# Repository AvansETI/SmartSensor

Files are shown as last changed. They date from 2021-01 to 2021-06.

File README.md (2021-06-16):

# SmartSensor
Author: _Maurice Snoeren (Lectoraat Smart Energy en Datascience & ICT)_


_Note: Current hardware version 1.0 is under test and some issues have been found ... it will be updated soon!_

De SmartSensor is een resultaat van verschillende onderzoeken sinds 2018. Focus is gegeven aan laag vermogen, controle over energiestromen en eenvoud. Deze SmartSensor wordt binnen onderzoek en onderwijs toegepast.

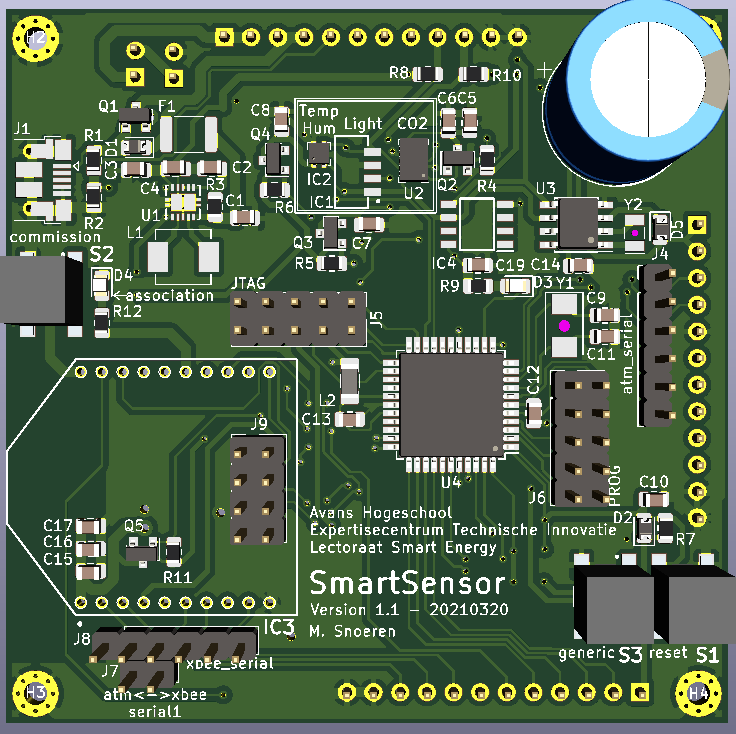
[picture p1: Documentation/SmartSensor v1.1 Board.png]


_3D generated model_

## Inleiding
Meten is weten! Het belang van meten en het verzamelen van informatie is wel bekend. Echter komt het vaak  voor dat data niet voorhanden is of dat de data van beschikbare systemen van onvoldoende kwaliteit is. Bestaande meetsystemen zijn vaak kostbaar en onvoldoende flexibel om de benodigde aanpassingen te maken die nodig zijn binnen de verschillende onderzoeken. De SmartSensor biedt een open platform, waarmee eenvoudig vele meetpunten in een omgeving geïnstalleerd kunnen worden. Het platform biedt de mogelijkheid eigen metingen toe te voegen. Uniek is dat het met de SmartSensor mogelijk wordt om met andere systemen te communiceren. Hierdoor wordt het mogelijk om tevens sturing aan te brengen. Een open platform dat binnen Avans Hogeschool wordt ingezet voor het onderzoek en onderwijs.

## SmartSensor specificatie
- Atmega324PB (Microcontroller)
- ATECC608B (Trusted Platform Module)
- Zigbee module (of nRF24L01)
- Real-time klok
- Omgevingslichtsensor (0lx t/m 167klx, 5mlx res.) 
- Temperatuursensor (±0.5˚C, -40 t/m 100˚C)
- Luchtvochtigheidssensor (±4.5 %RH)
- CO2 sensor (optional, eCO2, 400 t/m 8192ppm) 
- Interfaces: RS232 (3.3V), I2C en SPI
- Uitbreiden met header

## Werking
Alle SmartSensoren staan met elkaar in verbinding door middel van een Zigbee mesh-netwerk. Eén van de sensoren dient als een coördinator te dienen om de meet¬gegevens uit het systeem te krijgen. Via deze coördinator kunnen tevens commando’s naar de verschillende sensoren gestuurd worden om bijvoorbeeld een batterij op te laden of de verwarming in te stellen op 20 graden Celsius.

## Metingen bestaande gebouwen
Door op verschillende punten te meten, krijgt men inzicht in de energiehuishouding van het bestaande gebouw. In veel (oude) gebouwen zijn er geen of onvoldoende meetpunten aanwezig. Met behulp van de SmartSensor kunnen deze meetpunten eenvoudig worden toegevoegd. Doordat met gebouwsystemen communiceert kan worden, is het tevens mogelijk de gegevens van deze systemen te verzamelen en mee te nemen in de analyse.

## Verduurzaming gebouwen
Binnen gebouwen kan de SmartSensor meetpunten realiseren én communiceren met gebouwsystemen. Hierdoor wordt het mogelijk om een regelsysteem te realiseren waarbij het gebouw kan worden verduurzaamd. Gebouwsystemen worden dan aangestuurd op basis van verschillende metingen. Door de flexibiliteit van deze SmartSensor wordt het eenvoudig om verschillende strategieën en technieken te onderzoeken en ontdekken.

## Nieuwbouw
Nieuwe gebouwen worden vaak opgeleverd met veel sensoren en gebouwbeheersystemen. Meer meetpunten is vaak niet nodig. In dit geval is het mogelijk om de SmartSensor te gebruiken om het gebouw-beheersysteem te valideren. Door vele metingen aan te brengen krijgt men inzicht in de kwaliteit en effectiviteit van het bestaande systeem. Daarnaast is het mogelijk om met de SmartSensor eenvoudig extra meetpunten aan te brengen binnen het gebouw.

## Onderzoek
De SmartSensor speelt steeds meer een rol binnen de onderzoeken naar slimme duurzame energiesystemen, datascience vraagstukken en het zelfbewuste huis.

## Interesse
Interesse voor samenwerking? Neem contact met ons op!

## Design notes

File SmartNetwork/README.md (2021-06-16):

# SmartNetwork

The MQTT bus has been made smart with all kinds of messages and specific protocol.
It purpose is to create a safe sensor environment in which sensors can push data
and know that the integrity of the data is correct! This document is used to create
the documentation of this network.

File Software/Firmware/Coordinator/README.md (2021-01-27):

# Coordinator

Coordinator ontwikkeld om de data van de SmartSensor te ontvangen en die door te sturen over MQTT.
Voor development is Platformio gebruikt. Arduino Uno met een Zigbee Shield en een WiFi shield gebruikt. De Zigbee module moet wel ingesteld worden via DIGI XCTU. PANID, AT modus.

## Configuratie
Er is een config-template.h bestand in de include folder hier kan de WiFi en MQTT configuratie aangepast worden.

## Data 
Er wordt vanuit de Smart Sensor een JSON gestuurd die wordt uitgelezen met de Coordinator, in de Coordinator wordt er gecheckt of het een valide JSON is, zo ja dan wordt doorgestuurd naar een MQTT server die je hebt ingesteld in de configuratiebestand.

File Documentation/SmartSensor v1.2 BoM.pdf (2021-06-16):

SmartSensor v1.2 - 20210616
Item Qty Reference(s) | Value
1 | 4 C1, C3, C4, C17 | 10uF
2 | 9 C2, C5, C7, C8, C10, C12, C13, C14, C19 100nF
3 | 2 C6, C16 | 1uF
4 | 2 C9, C11 | 22pF
5 | 1 C15 | 8.2pF
6 | 1 C18 | 1F
7 | 3 D1, D2, D5 | D_Small
8 | 2 D3, D4 | RED
9 | 1 D6 | GREEN
10 | 1 F1 | Polyfuse_Small
12 | 1 IC1 | VEML7700-TT
13 | 1 IC2 | SHTC3
14 | 1 IC3 | XB24CZ7PIT-004
15 | 1 IC4 | ATECC608B-SSHDA-B
16 | 1 J1 | USB_B_Micro
26 | 1 L1 | 2.2uH @ 2,5A
27 | 1 L2 | 4.7uH
28 | 1 Q1 | DMG2301L
29 | 2 R1, R5 | 100k
30 | 1 R2 | 200k
31 | 1 R3 | 100
32 | 1 R7 | 10k
33 | 2 R8, R10 | 2.2k
34 | 3 R4, R9, R12 | 210
35 | 3 S1, S2, S3 | Push button
37 | 1 U1 | TPS63001
38 | 1 U2 | CCS811
39 | 1 U3 | MCP7940N-xSN
40 | 1 U4 | ATmega324PB-AU
41 | 1 Y1 | 20MHz
42 | 1 Y2 | Crystal

LibPart
Device:C_Small
Device:C_Small
Device:C_Small
Device:C_Small
Device:C_Small
Device:CP
Device:D_Small
Device:LED_Small
Device:LED_Small
Device:Polyfuse_Small
VEML7700-TT:VEML7700-TT
SamacSys_Parts:SHTC3
XB24CZ7PIT-004:XB24CZ7PIT-004 ATECC608B-SSHDA-B:ATECC608B-SSHDA-B Connector:USB_B_Micro
Device:L_Small
Device:L_Small
Transistor_FET:DMG2301L
Device:R_Small
Device:R_Small
Device:R_Small
Device:R_Small
Device:R_Small
Device:R_Small
Switch:SW_Push
Regulator_Switching:TPS63001 Sensor_Gas:CCS811
Timer:MCP7940N-xSN
MCU_Microchip_ATmega:ATmega324PB-AU Device:Crystal
Device:Crystal

Footprint | Manufacturer number
Capacitor_SMD:C_0805_2012Metric | 08056D106KAT4A (https://nl.mouser.com/ProductDetail/AVX/08056D106KAT4A/)
Capacitor_SMD:C_0805_2012Metric | 08055C104KAT2A (https://nl.mouser.com/ProductDetail/AVX/08055C104KAT2A/?qs=2ujN4bDBNE9mJvapP%252BjopA%3D%3D)
Capacitor_SMD:C_0805_2012Metric | C0805C105K4RAC (https://nl.mouser.com/ProductDetail/KEMET/C0805C105K4RAC/?qs=esDHISMOsl1mFkfcv5ZyKg%3D%3D)
Capacitor_SMD:C_0805_2012Metric | C0805C220K1HACTU (https://nl.mouser.com/ProductDetail/KEMET/C0805C220K1HACTU/?qs=W0yvOO0ixfHaPTgNXyVDyQ%3D%3D)
Capacitor_SMD:C_0805_2012Metric | C0805C829C1HACAUTO (https://nl.mouser.com/ProductDetail/KEMET/C0805C829C1HACAUTO/?qs=j%252B1pi9TdxUbIPgXf8DZVCg%3D%3D)
Capacitor_THT:CP_Radial_D14.0mm_P5.00mm | FGR0H105ZF (https://nl.mouser.com/ProductDetail/KEMET/FGR0H105ZF)
Diode_SMD:D_0805_2012Metric | NSVR1020MW2T1G (https://nl.mouser.com/ProductDetail/ON-Semiconductor/NSVR1020MW2T1G/)
LED_SMD:LED_0805_2012Metric | 150080SS75000 (https://nl.mouser.com/ProductDetail/Wurth-Elektronik/150080SS75000/?qs=LlUlMxKIyB2zzpiaOzrUdw%3D%3D)
LED_SMD:LED_0805_2012Metric | 150080GS75000 (https://nl.mouser.com/ProductDetail/Wurth-Elektronik/150080GS75000?qs=2kOmHSv6VfQRoTEZVk1mGA%3D%3D)
Fuse:Fuse_1812_4532Metric | 1812L300MR (https://nl.mouser.com/ProductDetail/Littelfuse/1812L300MR/?qs=fp%2Fo%2FcJ74okPZmQQaLnihw%3D%3D)
SmartSensor:VEML7700 | VEML7700-TT (https://nl.mouser.com/ProductDetail/Vishay-Semiconductors/VEML7700-TT/)
Package_DFN_QFN:AMS_QFN-4-1EP_2x2mm_P0.95mm_EP0.7x1.6mm | SHTC3 (https://nl.mouser.com/ProductDetail/Sensirion/SHTC3/?qs=y6ZabgHbY%252Bx3LlA87fqBwg%3D%3D)
XB24CZ7PIT-004:XB24CAPIT-001 | XB24CAWIT-001 (https://nl.mouser.com/ProductDetail/DIGI/XB24CAWIT-001)
ATECC608B-SSHDA-B:SOIC127P600X175-8N | ATECC608B-SSHDA-B (https://nl.mouser.com/ProductDetail/Microchip-Technology/ATECC608B-SSHDA-B/)
Connector_USB:USB_Micro-B_Amphenol_10103594-0001LF_Horizontal | 10103594-0001LF (https://nl.mouser.com/ProductDetail/Amphenol-FCI/10103594-0001LF)
Inductor_SMD:L_Vishay_IHLP-2020 | IHLP2020CZER2R2M11 (https://nl.mouser.com/ProductDetail/Vishay-Dale/IHLP2020CZER2R2M11/?qs=6luCnr706CzLTrsnHEyf2A%3D%3D)
Inductor_SMD:L_1206_3216Metric_Pad1.42x1.75mm_HandSolder | AIML-1206-4R7K-T (https://nl.mouser.com/ProductDetail/ABRACON/AIML-1206-4R7K-T?qs=1vO2EIVe%252BY78r6VHt%252BJPBQ%3D%3D)
Package_TO_SOT_SMD:SOT-23 | DMG2301LK-7 (https://nl.mouser.com/ProductDetail/Diodes-Incorporated/DMG2301LK-7/)
Resistor_SMD:R_0805_2012Metric | RN73H2ATTD1003B25 (https://nl.mouser.com/ProductDetail/KOA-Speer/RN73H2ATTD1003B25/?qs=pJKkPLTLvBjWE0HE4eur%2FQ%3D%3D)
Resistor_SMD:R_0805_2012Metric | RN73H2ATTD2003B25 (https://nl.mouser.com/ProductDetail/KOA-Speer/RN73H2ATTD2003B25/?qs=pJKkPLTLvBgFU%2FmyE2p5oQ%3D%3D)
Resistor_SMD:R_0805_2012Metric | RN73H2ATTD1000B25 (https://nl.mouser.com/ProductDetail/KOA-Speer/RN73H2ATTD1000B25/?qs=2eXtorxHpEIlNXER6IsTWA%3D%3D)
Resistor_SMD:R_0805_2012Metric | RN73H2ATTD1002B25 (https://nl.mouser.com/ProductDetail/KOA-Speer/RN73H2ATTD1002B25/?qs=ql2sB4ohmgACaXI2i5iccA%3D%3D)
Resistor_SMD:R_0805_2012Metric | RN73H2ATTD2201B10 (https://nl.mouser.com/ProductDetail/KOA-Speer/RN73H2ATTD2201B10/?qs=pJKkPLTLvBhl2%252Bb4W7%252BSoQ%3D%3D)
Resistor_SMD:R_0805_2012Metric | RN73H2ATTD2100B25 (https://nl.mouser.com/ProductDetail/KOA-Speer/RN73H2ATTD2100B25/?qs=pJKkPLTLvBgPs88Lelxj0w%3D%3D)
LL3301AF065QJ:LL3301FF065QJ | LL3301FF065QJ (https://nl.mouser.com/ProductDetail/E-Switch/LL3301FF065QJ/)
Package_SON:Texas_DRC0010J_ThermalVias | TPS63001DRCR (https://nl.mouser.com/ProductDetail/Texas-Instruments/TPS63001DRCR/?qs=QZuYiDxzHagn01UZf%2F%252B1Bw%3D%3D)
Package_LGA:AMS_LGA-10-1EP_2.7x4mm_P0.6mm | CCS811B-JOPR (https://nl.mouser.com/ProductDetail/ScioSense/CCS811B-JOPR/?qs=DPoM0jnrROVuOwd2mTsTQg%3D%3D)
Package_SO:SOIC-8_3.9x4.9mm_P1.27mm | MCP7940N-I/SN (https://nl.mouser.com/ProductDetail/Microchip-Technology/MCP7940N-I-SN/?qs=o%2FJGMiCJeCOTsMP4nrR5Uw%3D%3D)
Package_QFP:TQFP-44_10x10mm_P0.8mm | ATMEGA324PB-AU (https://nl.mouser.com/ProductDetail/556-ATMEGA324PBAU/)
Crystal:Crystal_SMD_Abracon_ABM3-2Pin_5.0x3.2mm | ABM3AIG-20.000MHZ-8-1R-T (https://nl.mouser.com/ProductDetail/ABRACON/ABM3AIG-20000MHZ-8-1R-T/?qs=uwxL4vQweFPdWRyKGKRehg%3D%3D)
Crystal:Crystal_SMD_G8-2Pin_3.2x1.5mm | ABS07W-32.768kHz-K-1-T (https://nl.mouser.com/ProductDetail/ABRACON/ABS07W-32768kHz-K-1-T/?qs=gt1LBUVyoHnktSE7ztRl4g%3D%3D)

Remark
Standard component can be found anywhere Standard component can be found anywhere Standard component can be found anywhere Standard component can be found anywhere Standard component can be found anywhere Normally not for Elines B.V.
Standard component can be found anywhere Standard component can be found anywhere Standard component can be found anywhere

Normally not for Elines B.V.

Aangepast naar 1206

Standard component can be found anywhere Standard component can be found anywhere Standard component can be found anywhere Standard component can be found anywhere Standard component can be found anywhere Standard component can be found anywhere

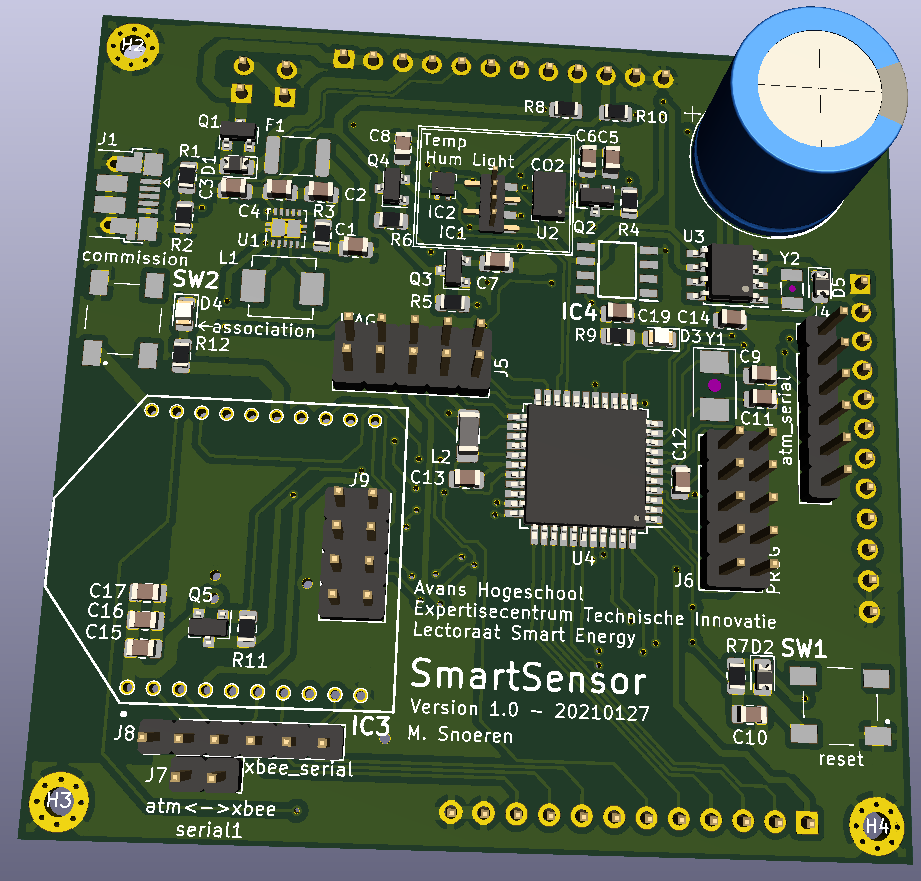
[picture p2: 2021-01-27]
Documentation/SmartSensor v1.0 Board.png

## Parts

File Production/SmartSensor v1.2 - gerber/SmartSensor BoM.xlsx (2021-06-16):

 |  | SmartSensor v1.2 - 20210616
Item | Qty | Reference(s) | Value | LibPart | Footprint | Manufacturer number | Remark
1 | 4 | C1, C3, C4, C17 | 10uF | Device:C_Small | Capacitor_SMD:C_0805_2012Metric | 08056D106KAT4A (https://nl.mouser.com/ProductDetail/AVX/08056D106KAT4A/) | Standard component can be found anywhere
2 | 9 | C2, C5, C7, C8, C10, C12, C13, C14, C19 | 100nF | Device:C_Small | Capacitor_SMD:C_0805_2012Metric | 08055C104KAT2A (https://nl.mouser.com/ProductDetail/AVX/08055C104KAT2A/?qs=2ujN4bDBNE9mJvapP%252BjopA%3D%3D) | Standard component can be found anywhere
3 | 2 | C6, C16 | 1uF | Device:C_Small | Capacitor_SMD:C_0805_2012Metric | C0805C105K4RAC (https://nl.mouser.com/ProductDetail/KEMET/C0805C105K4RAC/?qs=esDHISMOsl1mFkfcv5ZyKg%3D%3D) | Standard component can be found anywhere
4 | 2 | C9, C11 | 22pF | Device:C_Small | Capacitor_SMD:C_0805_2012Metric | C0805C220K1HACTU (https://nl.mouser.com/ProductDetail/KEMET/C0805C220K1HACTU/?qs=W0yvOO0ixfHaPTgNXyVDyQ%3D%3D) | Standard component can be found anywhere
5 | 1 | C15 | 8.2pF | Device:C_Small | Capacitor_SMD:C_0805_2012Metric | C0805C829C1HACAUTO (https://nl.mouser.com/ProductDetail/KEMET/C0805C829C1HACAUTO/?qs=j%252B1pi9TdxUbIPgXf8DZVCg%3D%3D) | Standard component can be found anywhere
6 | 1 | C18 | 1F | Device:CP | Capacitor_THT:CP_Radial_D14.0mm_P5.00mm | FGR0H105ZF (https://nl.mouser.com/ProductDetail/KEMET/FGR0H105ZF) | Normally not for Elines B.V.
7 | 3 | D1, D2, D5 | D_Small | Device:D_Small | Diode_SMD:D_0805_2012Metric | NSVR1020MW2T1G (https://nl.mouser.com/ProductDetail/ON-Semiconductor/NSVR1020MW2T1G/) | Standard component can be found anywhere
8 | 2 | D3, D4 | RED | Device:LED_Small | LED_SMD:LED_0805_2012Metric | 150080SS75000 (https://nl.mouser.com/ProductDetail/Wurth-Elektronik/150080SS75000/?qs=LlUlMxKIyB2zzpiaOzrUdw%3D%3D) | Standard component can be found anywhere
9 | 1 | D6 | GREEN | Device:LED_Small | LED_SMD:LED_0805_2012Metric | 150080GS75000 (https://nl.mouser.com/ProductDetail/Wurth-Elektronik/150080GS75000?qs=2kOmHSv6VfQRoTEZVk1mGA%3D%3D) | Standard component can be found anywhere
10 | 1 | F1 | Polyfuse_Small | Device:Polyfuse_Small | Fuse:Fuse_1812_4532Metric | 1812L300MR (https://nl.mouser.com/ProductDetail/Littelfuse/1812L300MR/?qs=fp%2Fo%2FcJ74okPZmQQaLnihw%3D%3D)
12 | 1 | IC1 | VEML7700-TT | VEML7700-TT:VEML7700-TT | SmartSensor:VEML7700 | VEML7700-TT (https://nl.mouser.com/ProductDetail/Vishay-Semiconductors/VEML7700-TT/)
13 | 1 | IC2 | SHTC3 | SamacSys_Parts:SHTC3 | Package_DFN_QFN:AMS_QFN-4-1EP_2x2mm_P0.95mm_EP0.7x1.6mm | SHTC3 (https://nl.mouser.com/ProductDetail/Sensirion/SHTC3/?qs=y6ZabgHbY%252Bx3LlA87fqBwg%3D%3D)
14 | 1 | IC3 | XB24CZ7PIT-004 | XB24CZ7PIT-004:XB24CZ7PIT-004 | XB24CZ7PIT-004:XB24CAPIT-001 | XB24CAWIT-001 (https://nl.mouser.com/ProductDetail/DIGI/XB24CAWIT-001) | Normally not for Elines B.V.
15 | 1 | IC4 | ATECC608B-SSHDA-B | ATECC608B-SSHDA-B:ATECC608B-SSHDA-B | ATECC608B-SSHDA-B:SOIC127P600X175-8N | ATECC608B-SSHDA-B (https://nl.mouser.com/ProductDetail/Microchip-Technology/ATECC608B-SSHDA-B/)
16 | 1 | J1 | USB_B_Micro | Connector:USB_B_Micro | Connector_USB:USB_Micro-B_Amphenol_10103594-0001LF_Horizontal | 10103594-0001LF (https://nl.mouser.com/ProductDetail/Amphenol-FCI/10103594-0001LF)
26 | 1 | L1 | 2.2uH @ 2,5A | Device:L_Small | Inductor_SMD:L_Vishay_IHLP-2020 | IHLP2020CZER2R2M11 (https://nl.mouser.com/ProductDetail/Vishay-Dale/IHLP2020CZER2R2M11/?qs=6luCnr706CzLTrsnHEyf2A%3D%3D)
27 | 1 | L2 | 4.7uH | Device:L_Small | Inductor_SMD:L_1206_3216Metric_Pad1.42x1.75mm_HandSolder | AIML-1206-4R7K-T (https://nl.mouser.com/ProductDetail/ABRACON/AIML-1206-4R7K-T?qs=1vO2EIVe%252BY78r6VHt%252BJPBQ%3D%3D) | Aangepast naar 1206
28 | 1 | Q1 | DMG2301L | Transistor_FET:DMG2301L | Package_TO_SOT_SMD:SOT-23 | DMG2301LK-7 (https://nl.mouser.com/ProductDetail/Diodes-Incorporated/DMG2301LK-7/)
29 | 2 | R1, R5 | 100k | Device:R_Small | Resistor_SMD:R_0805_2012Metric | RN73H2ATTD1003B25 (https://nl.mouser.com/ProductDetail/KOA-Speer/RN73H2ATTD1003B25/?qs=pJKkPLTLvBjWE0HE4eur%2FQ%3D%3D) | Standard component can be found anywhere
30 | 1 | R2 | 200k | Device:R_Small | Resistor_SMD:R_0805_2012Metric | RN73H2ATTD2003B25 (https://nl.mouser.com/ProductDetail/KOA-Speer/RN73H2ATTD2003B25/?qs=pJKkPLTLvBgFU%2FmyE2p5oQ%3D%3D) | Standard component can be found anywhere
31 | 1 | R3 | 100 | Device:R_Small | Resistor_SMD:R_0805_2012Metric | RN73H2ATTD1000B25 (https://nl.mouser.com/ProductDetail/KOA-Speer/RN73H2ATTD1000B25/?qs=2eXtorxHpEIlNXER6IsTWA%3D%3D) | Standard component can be found anywhere
32 | 1 | R7 | 10k | Device:R_Small | Resistor_SMD:R_0805_2012Metric | RN73H2ATTD1002B25 (https://nl.mouser.com/ProductDetail/KOA-Speer/RN73H2ATTD1002B25/?qs=ql2sB4ohmgACaXI2i5iccA%3D%3D) | Standard component can be found anywhere
33 | 2 | R8, R10 | 2.2k | Device:R_Small | Resistor_SMD:R_0805_2012Metric | RN73H2ATTD2201B10 (https://nl.mouser.com/ProductDetail/KOA-Speer/RN73H2ATTD2201B10/?qs=pJKkPLTLvBhl2%252Bb4W7%252BSoQ%3D%3D) | Standard component can be found anywhere
34 | 3 | R4, R9, R12 | 210 | Device:R_Small | Resistor_SMD:R_0805_2012Metric | RN73H2ATTD2100B25 (https://nl.mouser.com/ProductDetail/KOA-Speer/RN73H2ATTD2100B25/?qs=pJKkPLTLvBgPs88Lelxj0w%3D%3D) | Standard component can be found anywhere
35 | 3 | S1, S2, S3 | Push button | Switch:SW_Push | LL3301AF065QJ:LL3301FF065QJ | LL3301FF065QJ (https://nl.mouser.com/ProductDetail/E-Switch/LL3301FF065QJ/)
37 | 1 | U1 | TPS63001 | Regulator_Switching:TPS63001 | Package_SON:Texas_DRC0010J_ThermalVias | TPS63001DRCR (https://nl.mouser.com/ProductDetail/Texas-Instruments/TPS63001DRCR/?qs=QZuYiDxzHagn01UZf%2F%252B1Bw%3D%3D)
38 | 1 | U2 | CCS811 | Sensor_Gas:CCS811 | Package_LGA:AMS_LGA-10-1EP_2.7x4mm_P0.6mm | CCS811B-JOPR (https://nl.mouser.com/ProductDetail/ScioSense/CCS811B-JOPR/?qs=DPoM0jnrROVuOwd2mTsTQg%3D%3D)
39 | 1 | U3 | MCP7940N-xSN | Timer:MCP7940N-xSN | Package_SO:SOIC-8_3.9x4.9mm_P1.27mm | MCP7940N-I/SN (https://nl.mouser.com/ProductDetail/Microchip-Technology/MCP7940N-I-SN/?qs=o%2FJGMiCJeCOTsMP4nrR5Uw%3D%3D)
40 | 1 | U4 | ATmega324PB-AU | MCU_Microchip_ATmega:ATmega324PB-AU | Package_QFP:TQFP-44_10x10mm_P0.8mm | ATMEGA324PB-AU (https://nl.mouser.com/ProductDetail/556-ATMEGA324PBAU/)
41 | 1 | Y1 | 20MHz | Device:Crystal | Crystal:Crystal_SMD_Abracon_ABM3-2Pin_5.0x3.2mm | ABM3AIG-20.000MHZ-8-1R-T (https://nl.mouser.com/ProductDetail/ABRACON/ABM3AIG-20000MHZ-8-1R-T/?qs=uwxL4vQweFPdWRyKGKRehg%3D%3D)
42 | 1 | Y2 | Crystal | Device:Crystal | Crystal:Crystal_SMD_G8-2Pin_3.2x1.5mm | ABS07W-32.768kHz-K-1-T (https://nl.mouser.com/ProductDetail/ABRACON/ABS07W-32768kHz-K-1-T/?qs=gt1LBUVyoHnktSE7ztRl4g%3D%3D)

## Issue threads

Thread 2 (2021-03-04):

Hardware version 1.0 issues

macsnoeren, 2021-03-04:
The following issues have been found that will be fixed as soon as possible:
- USB connector wrong type. At this moment the pins have been mirrored.
- Tacticle switches wrong package. At this moment 90 degrees rotated that results in continuous reset.
- All MOSFETs have been connected reversed, resulting in always switched one via de diode.
- The light sensor has been connected reversed. Make sure the correct package is used!

macsnoeren, 2021-03-19:
Progress:

- USB connector wrong type => Indeed wrong type orderen. BOM updated. (check!)
- Tacticle switches wrong package. At this moment 90 degrees rotated that results in continuous reset.
- All MOSFETs have been connected reversed, resulting in always switched one via de diode => All MOSFETs mirrored. (check!)
- The light sensor has been connected reversed. Make sure the correct package is used => Light sensor was correctly connected.

macsnoeren, 2021-03-20:
Progress:

- USB connector wrong type => Indeed wrong type orderen. BOM updated. (check!)
- Tacticle switches wrong package. At this moment 90 degrees rotated that results in continuous reset. => New package (check!)
- All MOSFETs have been connected reversed, resulting in always switched one via de diode => All MOSFETs mirrored. (check!)
- The light sensor has been connected reversed. Make sure the correct package is used => Light sensor was correctly connected. => new package (check!)

macsnoeren, 2021-03-20:
Fixed the hardware, added a button.

Closed 2021-03-20.

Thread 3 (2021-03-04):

i2c not working properly

macsnoeren, 2021-03-04:
At this moment it is not possible to read and write to the various ICs.

macsnoeren, 2021-03-04:
Today, the board have been checked and it has been found that the light sensor has been place reversed. This IC has been removed for the moment. All other connections have been checked and it seems to be correctly connected.

macsnoeren, 2021-03-04:
The signals of the i2c bus have been checked using an oscilloscope. The signals are okay. When the CO2 sensor is selected, weird things happen. After the data, the SDA bus is pulled low by the device.I think, while we perform a read, the IC waits on a clock to give the data back the processor using SDA.

Try to read the following bytes and check if the sensor pushed data back!

macsnoeren, 2021-03-04:
TODO: The nWake pin of the CO2 sensor is not yet used. This pin needs to be driven low before the i2c bus is used. All GPIO pins of the Atmel are set to input without pullup when started up. Try to set the pinmode to output and drive it low at start up.

macsnoeren, 2021-03-04:
From the datasheet is has been found that the IC SHTC3 has a device address 0x70: 111 0000. So, when reading it will be 1110 0000 => E0. And writhing 1110 0001 => E1. Therefore, the address has been changed to E0 in the board support. Please use the address E0.

macsnoeren, 2021-03-04:
TODO: Please use 100kHz clock for the "normal mode" i2c operation.

macsnoeren, 2021-03-19:
FloBo, are you able to put some info in this issue page, while everything is working now. Except the CO2 sensor.

macsnoeren, 2021-03-21:
Found this at: [https://www.ti.com/lit/an/scaa106/scaa106.pdf?ts=1616331517789&ref_url=https%253A%252F%252Fwww.google.com%252F](https://www.ti.com/lit/an/scaa106/scaa106.pdf?ts=1616331517789&ref_url=https%253A%252F%252Fwww.google.com%252F)

Sorry, it is the definition of I2C that slaves must 'pull' the clock-line low to 'pace' a master when return-data is not immediately available.  And in ALL cases of microcontroller I2C slave implementations, they ALWAYS pull the clock-line low at every access as uC firmware must supply the return data 'after some time'.  Once you have initialized the K22F into I2C 'slave' mode, you are going to have to be sure that it is ALWAYS 'ready' to return data for I2C transactions addressed to it, else it will indeed permanently stall the whole I2C bus. If you don't want the K22F reacting to such transactions, you have to disable this slave mode (for at least those time periods).  Does your K22F respond to addressed transactions 'fully normally' when properly enabled?

Maybe, the CO2 sensor is busy initializing. We need to investigate this a bit more.

macsnoeren, 2021-03-21:
Some documentation:
[https://www.ti.com/lit/an/scaa106/scaa106.pdf?ts=1616331517789&ref_url=https%253A%252F%252Fwww.google.com%252F](https://www.ti.com/lit/an/scaa106/scaa106.pdf?ts=1616331517789&ref_url=https%253A%252F%252Fwww.google.com%252F)

macsnoeren, 2021-03-26:
Both I2C-busses are working properly. CO2 sensor is not working still. New issue will be created for this one.

Closed 2021-03-26.

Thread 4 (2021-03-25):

Hardware: SuperCap not current limited!

macsnoeren, 2021-03-25:
The used supercap is not current limited and will blow the fuse. Please make the hardware fix and put a resistor. In the new design, the resistor will be implemented.

macsnoeren, 2021-03-26:
Found out that the internal resistance is large and that means the current is already limited by the supercap itself.

Closed 2021-03-26.

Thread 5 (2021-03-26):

CO2 CSS811 not working

macsnoeren, 2021-03-26:
The CO2 sensor is not working on the board. It does not give an ACK and pulls for 25ms the datalines to low. When another CO2 break out board is connected, it works correctly. We assume that the hardware is failing at this moment.

Some docs:
https://cdn-learn.adafruit.com/downloads/pdf/adafruit-ccs811-air-quality-sensor.pdf
https://www.distrelec.nl/Web/Downloads/_t/ds/3566_eng_tds.pdf

macsnoeren, 2021-04-16:
The Adafruit CSS811 is working correctly, waiting on the prototypes.

macsnoeren, 2021-06-16:
Solved, everything is working now.

Closed 2021-06-16.

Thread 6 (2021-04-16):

Hardware v1.1 silkscreen incorrect VEML

macsnoeren, 2021-04-16:
Hardware silkscreen incorrect VEML.

macsnoeren, 2021-06-16:
Solved, everything is working now.

Closed 2021-06-16.

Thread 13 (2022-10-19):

SmartNetwork crash

macsnoeren, 2022-10-19:
```
|SmartNet | During handling of the above exception, another exception occurred:
0|SmartNet |
0|SmartNet | Traceback (most recent call last):
0|SmartNet |   File "/usr/lib/python3.8/threading.py", line 932, in _bootstrap_inner
0|SmartNet |     self.run()
0|SmartNet |   File "/usr/lib/python3.8/threading.py", line 870, in run
0|SmartNet |     self._target(*self._args, **self._kwargs)
0|SmartNet |   File "/home/maurice/.local/lib/python3.8/site-packages/paho/mqtt/client.py", line 3591, in _thread_main
0|SmartNet |     self.loop_forever(retry_first_connection=True)
0|SmartNet |   File "/home/maurice/.local/lib/python3.8/site-packages/paho/mqtt/client.py", line 1756, in loop_forever
0|SmartNet |     rc = self._loop(timeout)
0|SmartNet |   File "/home/maurice/.local/lib/python3.8/site-packages/paho/mqtt/client.py", line 1164, in _loop
0|SmartNet |     rc = self.loop_read()
0|SmartNet |   File "/home/maurice/.local/lib/python3.8/site-packages/paho/mqtt/client.py", line 1556, in loop_read
0|SmartNet |     rc = self._packet_read()
0|SmartNet |   File "/home/maurice/.local/lib/python3.8/site-packages/paho/mqtt/client.py", line 2439, in _packet_read
0|SmartNet |     rc = self._packet_handle()
0|SmartNet |   File "/home/maurice/.local/lib/python3.8/site-packages/paho/mqtt/client.py", line 3033, in _packet_handle
0|SmartNet |     return self._handle_publish()
0|SmartNet |   File "/home/maurice/.local/lib/python3.8/site-packages/paho/mqtt/client.py", line 3327, in _handle_publish
0|SmartNet |     self._handle_on_message(message)
0|SmartNet |   File "/home/maurice/.local/lib/python3.8/site-packages/paho/mqtt/client.py", line 3570, in _handle_on_message
0|SmartNet |     on_message(self, self._userdata, message)
0|SmartNet |   File "/home/maurice/SmartSensor/SmartNetwork/smartnetwork/smartnetwork/smartnetwork.py", line 79, in <lambda>
0|SmartNet |     self.mqtt.on_message    = lambda client, userdata, msg:       self.mqtt_on_message(client, userdata, msg)
0|SmartNet |   File "/home/maurice/SmartSensor/SmartNetwork/smartnetwork/smartnetwork/smartnetwork.py", line 119, in mqtt_on_message
0|SmartNet |     self.process_node_data(plJson)
0|SmartNet |   File "/home/maurice/SmartSensor/SmartNetwork/smartnetwork/smartnetwork/smartnetwork.py", line 231, in process_node_data
0|SmartNet |     node = self.get_node_from_id(data["id"])
0|SmartNet |   File "/home/maurice/SmartSensor/SmartNetwork/smartnetwork/smartnetwork/smartnetwork.py", line 172, in get_node_from_id
0|SmartNet |     records = self.query.query(org=self.org, query=query)
0|SmartNet |   File "/home/maurice/.local/lib/python3.8/site-packages/influxdb_client/client/query_api.py", line 100, in query
0|SmartNet |     response = self._query_api.post_query(org=org, query=self._create_query(query, self.default_dialect, params),
0|SmartNet |   File "/home/maurice/.local/lib/python3.8/site-packages/influxdb_client/service/query_service.py", line 258, in post_query
0|SmartNet |     (data) = self.post_query_with_http_info(**kwargs)  # noqa: E501
0|SmartNet |   File "/home/maurice/.local/lib/python3.8/site-packages/influxdb_client/service/query_service.py", line 338, in post_query_with_http_info
0|SmartNet |     return self.api_client.call_api(
0|SmartNet |   File "/home/maurice/.local/lib/python3.8/site-packages/influxdb_client/api_client.py", line 341, in call_api
0|SmartNet |     return self.__call_api(resource_path, method,
0|SmartNet |   File "/home/maurice/.local/lib/python3.8/site-packages/influxdb_client/api_client.py", line 171, in __call_api
0|SmartNet |     response_data = self.request(
0|SmartNet |   File "/home/maurice/.local/lib/python3.8/site-packages/influxdb_client/api_client.py", line 386, in request
0|SmartNet |     return self.rest_client.POST(url,
0|SmartNet |   File "/home/maurice/.local/lib/python3.8/site-packages/influxdb_client/rest.py", line 304, in POST
0|SmartNet |     return self.request("POST", url,
0|SmartNet |   File "/home/maurice/.local/lib/python3.8/site-packages/influxdb_client/rest.py", line 183, in request
0|SmartNet |     r = self.pool_manager.request(
0|SmartNet |   File "/usr/lib/python3/dist-packages/urllib3/request.py", line 79, in request
0|SmartNet |     return self.request_encode_body(
0|SmartNet |   File "/usr/lib/python3/dist-packages/urllib3/request.py", line 171, in request_encode_body
0|SmartNet |     return self.urlopen(method, url, **extra_kw)
0|SmartNet |   File "/usr/lib/python3/dist-packages/urllib3/poolmanager.py", line 330, in urlopen
0|SmartNet |     response = conn.urlopen(method, u.request_uri, **kw)
0|SmartNet |   File "/usr/lib/python3/dist-packages/urllib3/connectionpool.py", line 719, in urlopen
0|SmartNet |     retries = retries.increment(
0|SmartNet |   File "/usr/lib/python3/dist-packages/urllib3/util/retry.py", line 376, in increment
0|SmartNet |     raise six.reraise(type(error), error, _stacktrace)
0|SmartNet |   File "/usr/lib/python3/dist-packages/six.py", line 703, in reraise
0|SmartNet |     raise value
0|SmartNet |   File "/usr/lib/python3/dist-packages/urllib3/connectionpool.py", line 665, in urlopen
0|SmartNet |     httplib_response = self._make_request(
0|SmartNet |   File "/usr/lib/python3/dist-packages/urllib3/connectionpool.py", line 387, in _make_request
0|SmartNet |     conn.request(method, url, **httplib_request_kw)
0|SmartNet |   File "/usr/lib/python3.8/http/client.py", line 1256, in request
0|SmartNet |     self._send_request(method, url, body, headers, encode_chunked)
0|SmartNet |   File "/usr/lib/python3.8/http/client.py", line 1302, in _send_request
0|SmartNet |     self.endheaders(body, encode_chunked=encode_chunked)
0|SmartNet |   File "/usr/lib/python3.8/http/client.py", line 1251, in endheaders
0|SmartNet |     self._send_output(message_body, encode_chunked=encode_chunked)
0|SmartNet |   File "/usr/lib/python3.8/http/client.py", line 1011, in _send_output
0|SmartNet |     self.send(msg)
0|SmartNet |   File "/usr/lib/python3.8/http/client.py", line 951, in send
0|SmartNet |     self.connect()
0|SmartNet |   File "/usr/lib/python3/dist-packages/urllib3/connection.py", line 187, in connect
0|SmartNet |     conn = self._new_conn()
0|SmartNet |   File "/usr/lib/python3/dist-packages/urllib3/connection.py", line 171, in _new_conn
0|SmartNet |     raise NewConnectionError(
0|SmartNet | urllib3.exceptions.NewConnectionError: <urllib3.connection.HTTPConnection object at 0x7fe0720dc4f0>: Failed to establish a new connection: [Errno 111] Connection refused
```

macsnoeren, 2022-10-19:
Same issue as #12

macsnoeren, 2022-10-19:
Close this issue and work on #12

Closed 2022-10-19.

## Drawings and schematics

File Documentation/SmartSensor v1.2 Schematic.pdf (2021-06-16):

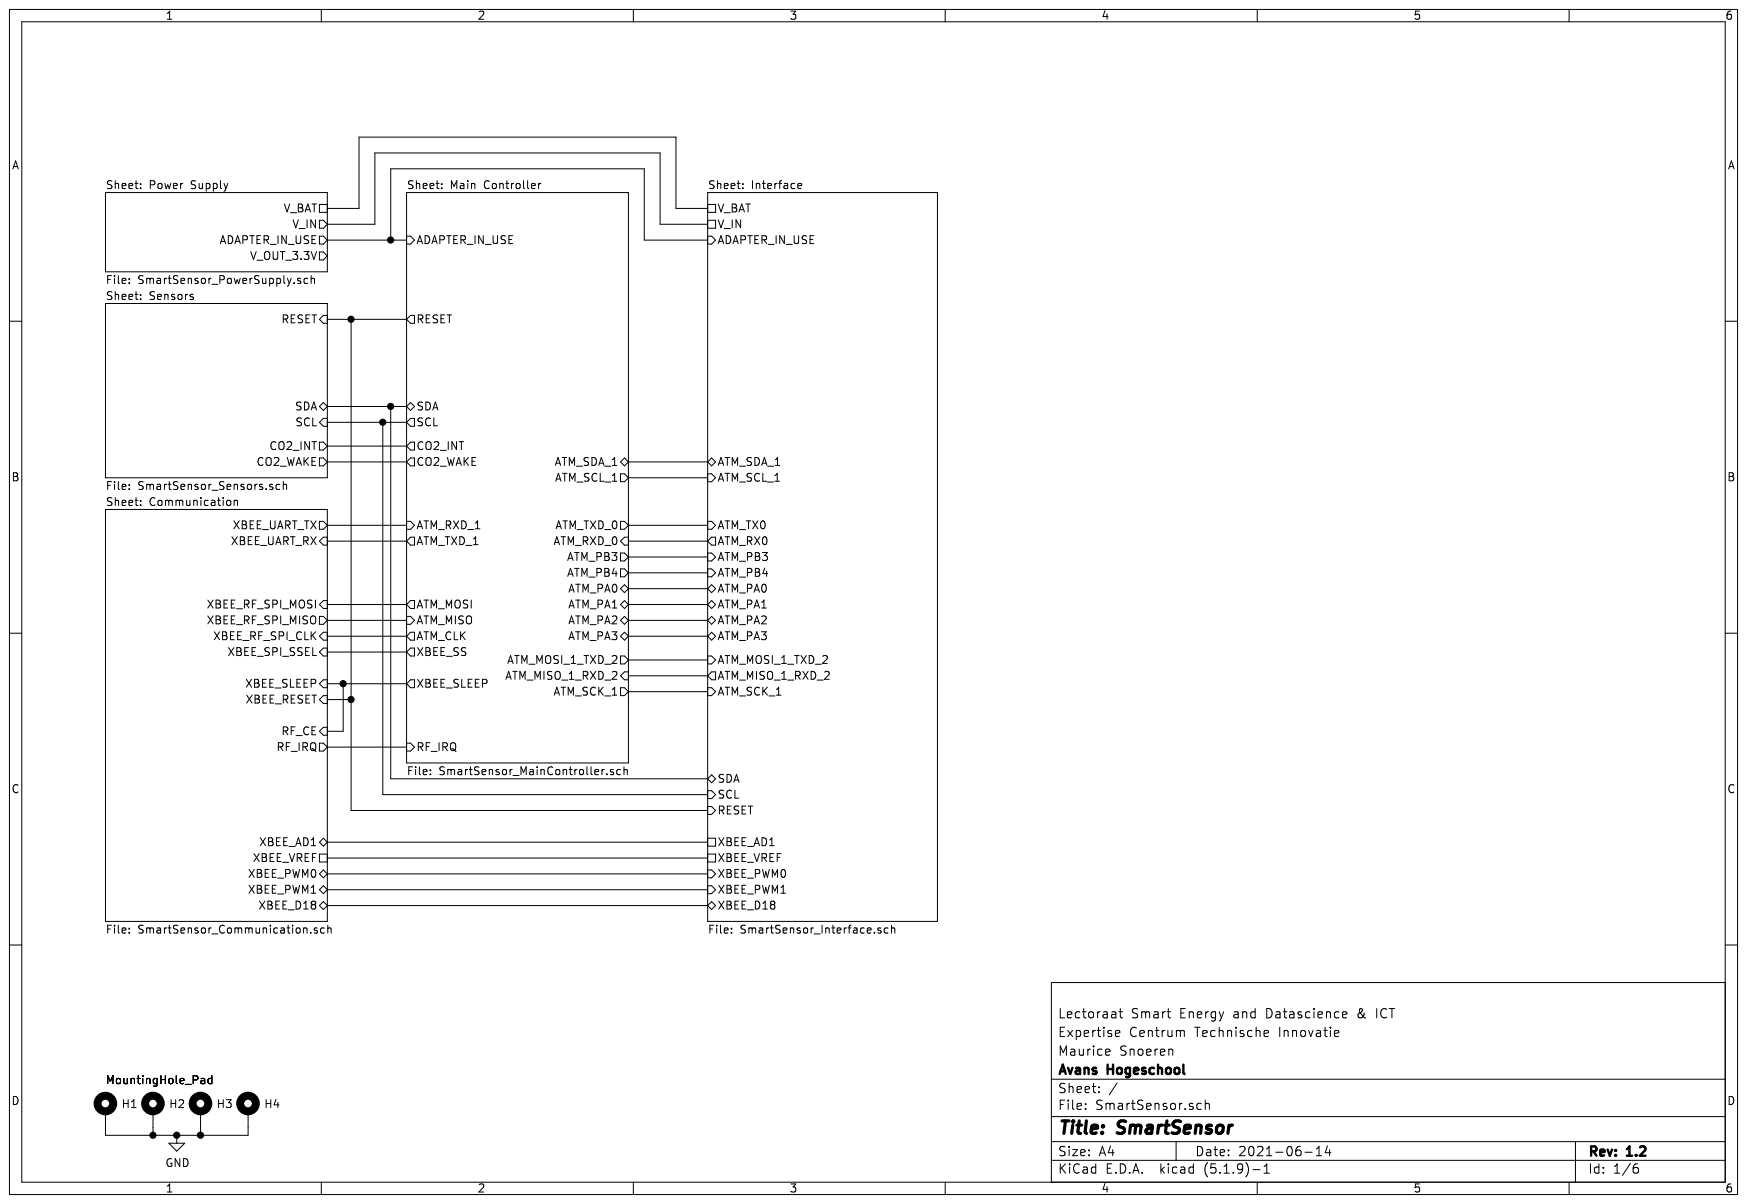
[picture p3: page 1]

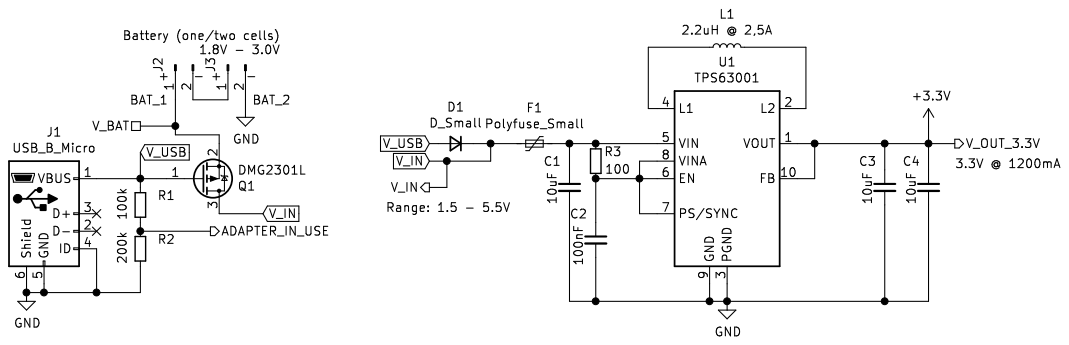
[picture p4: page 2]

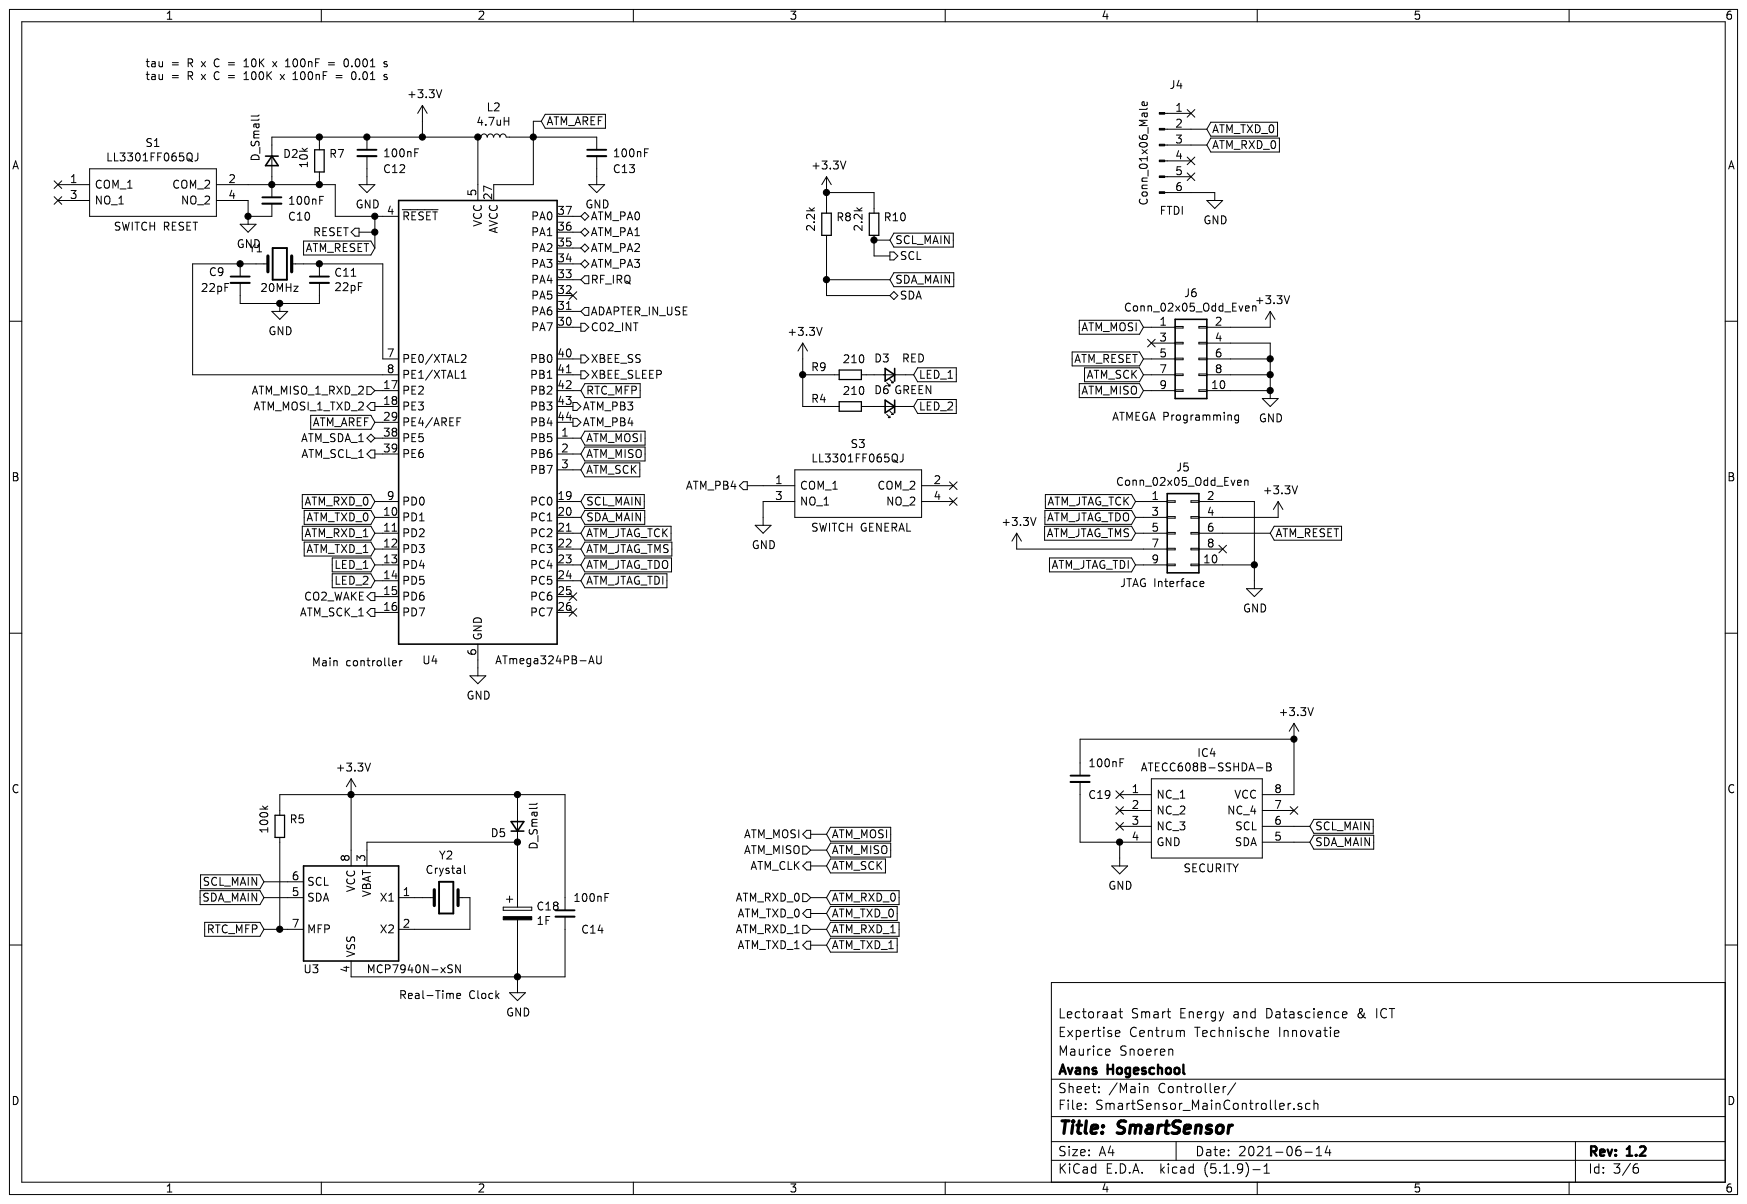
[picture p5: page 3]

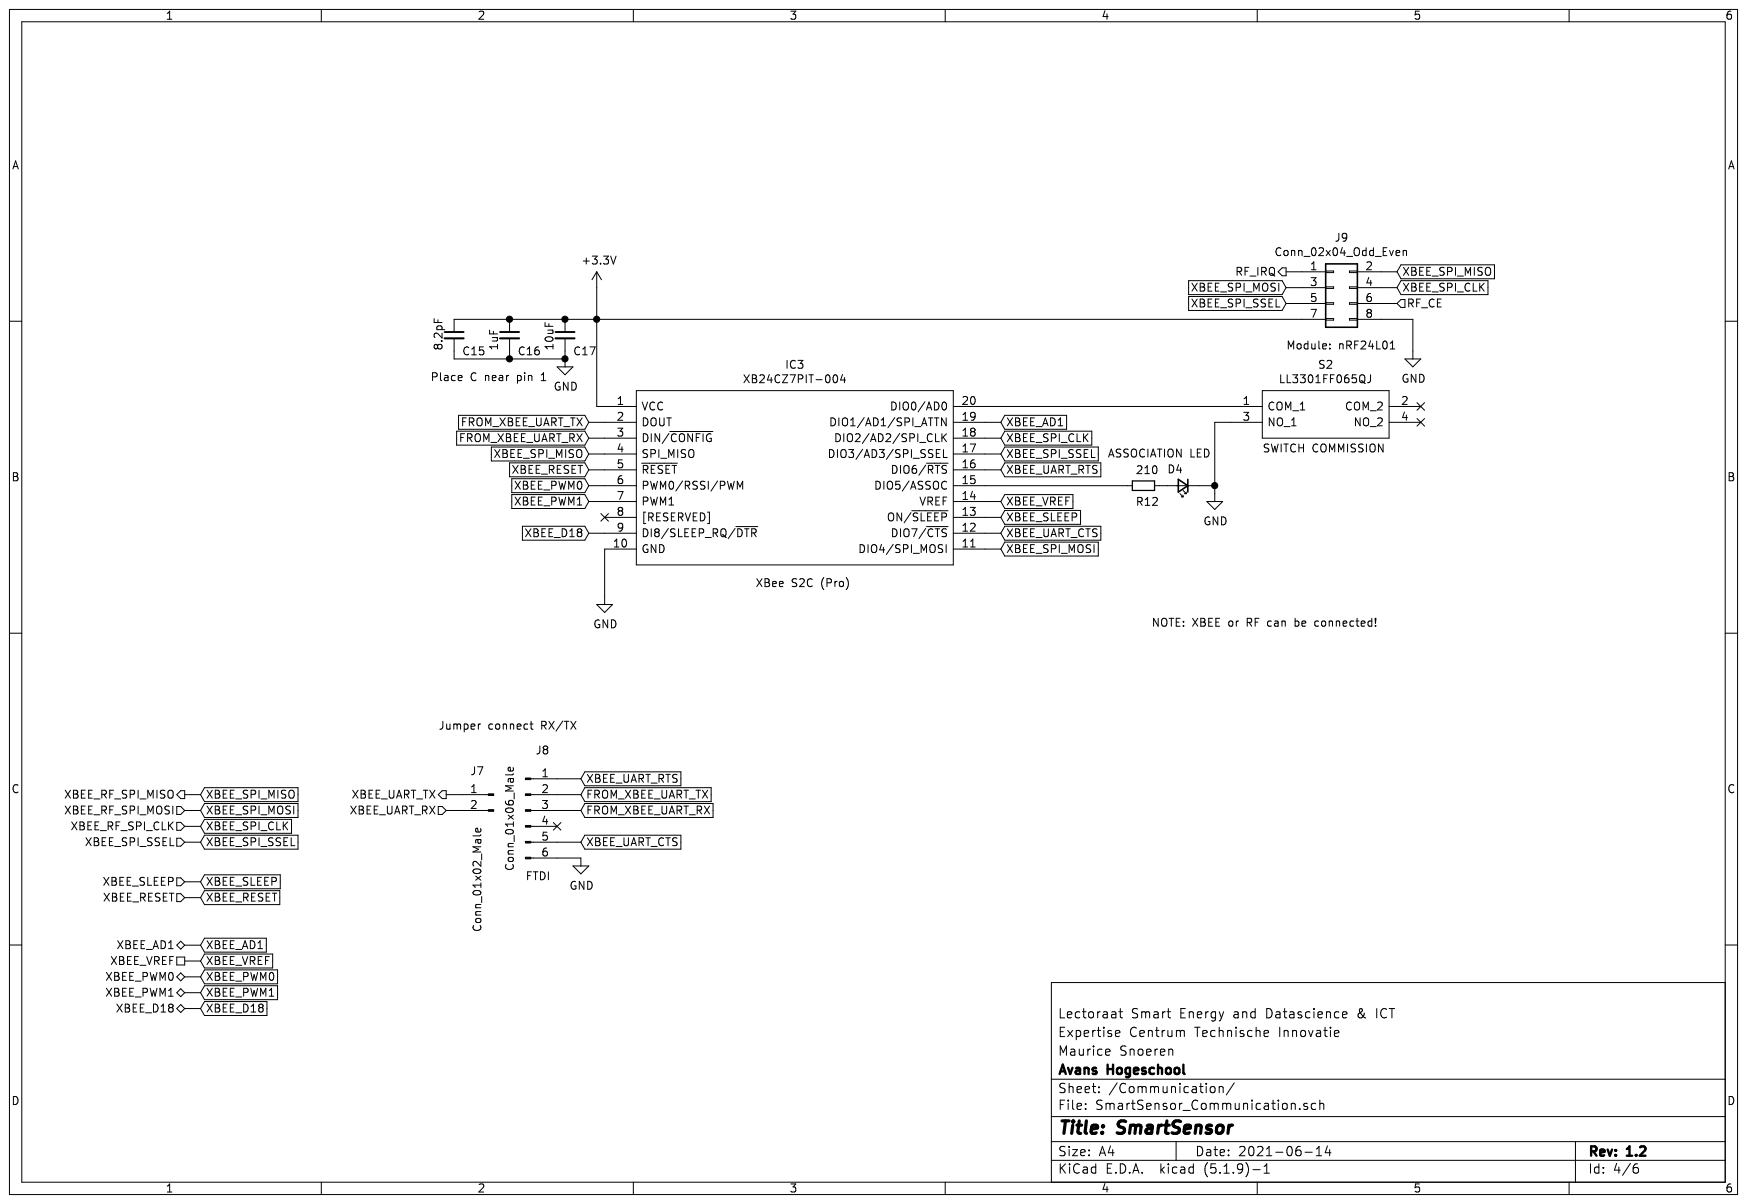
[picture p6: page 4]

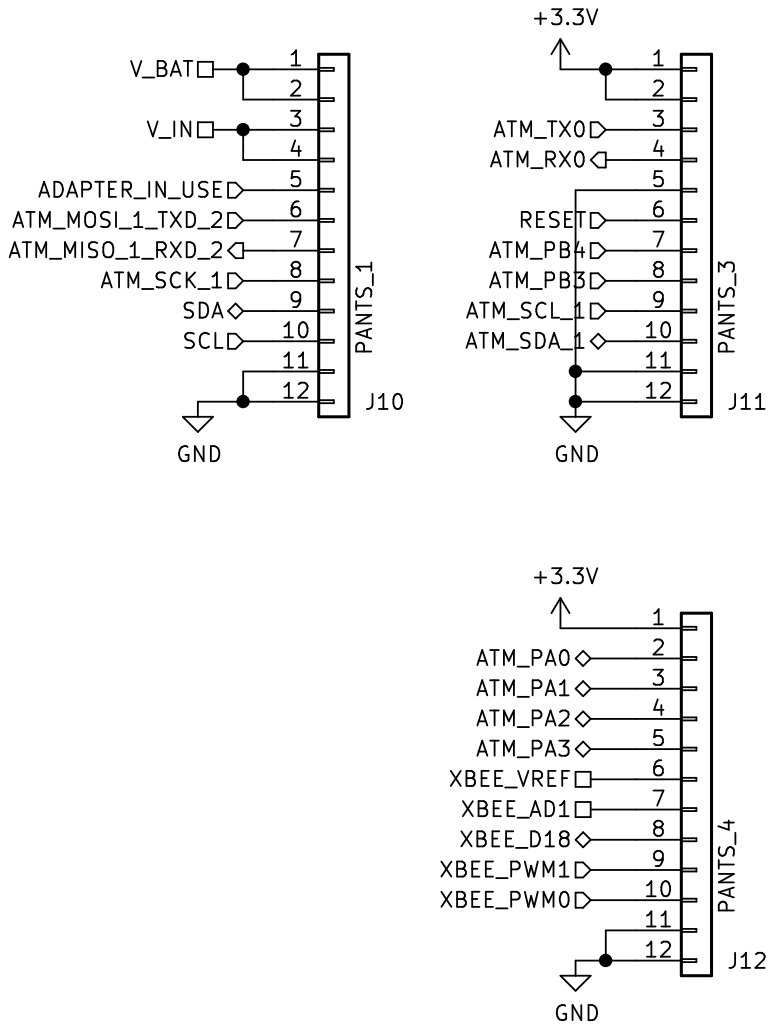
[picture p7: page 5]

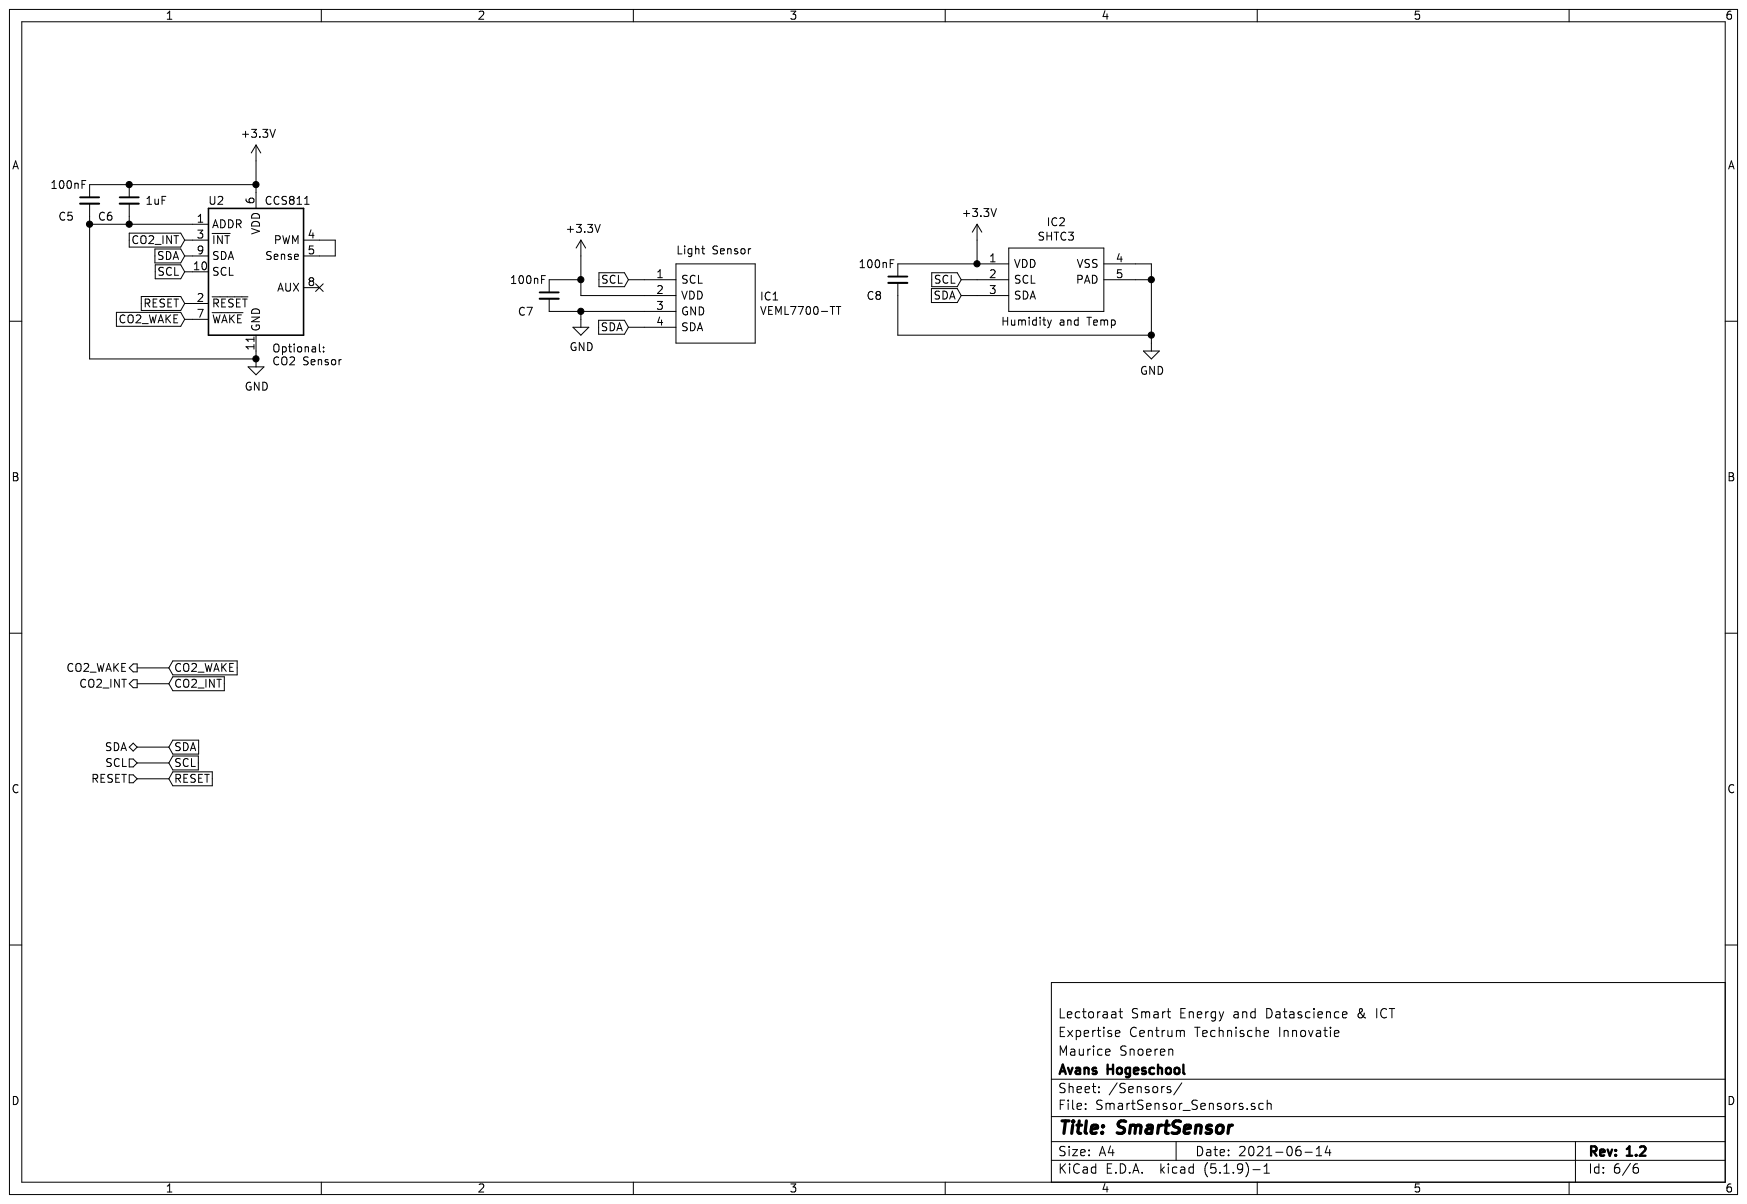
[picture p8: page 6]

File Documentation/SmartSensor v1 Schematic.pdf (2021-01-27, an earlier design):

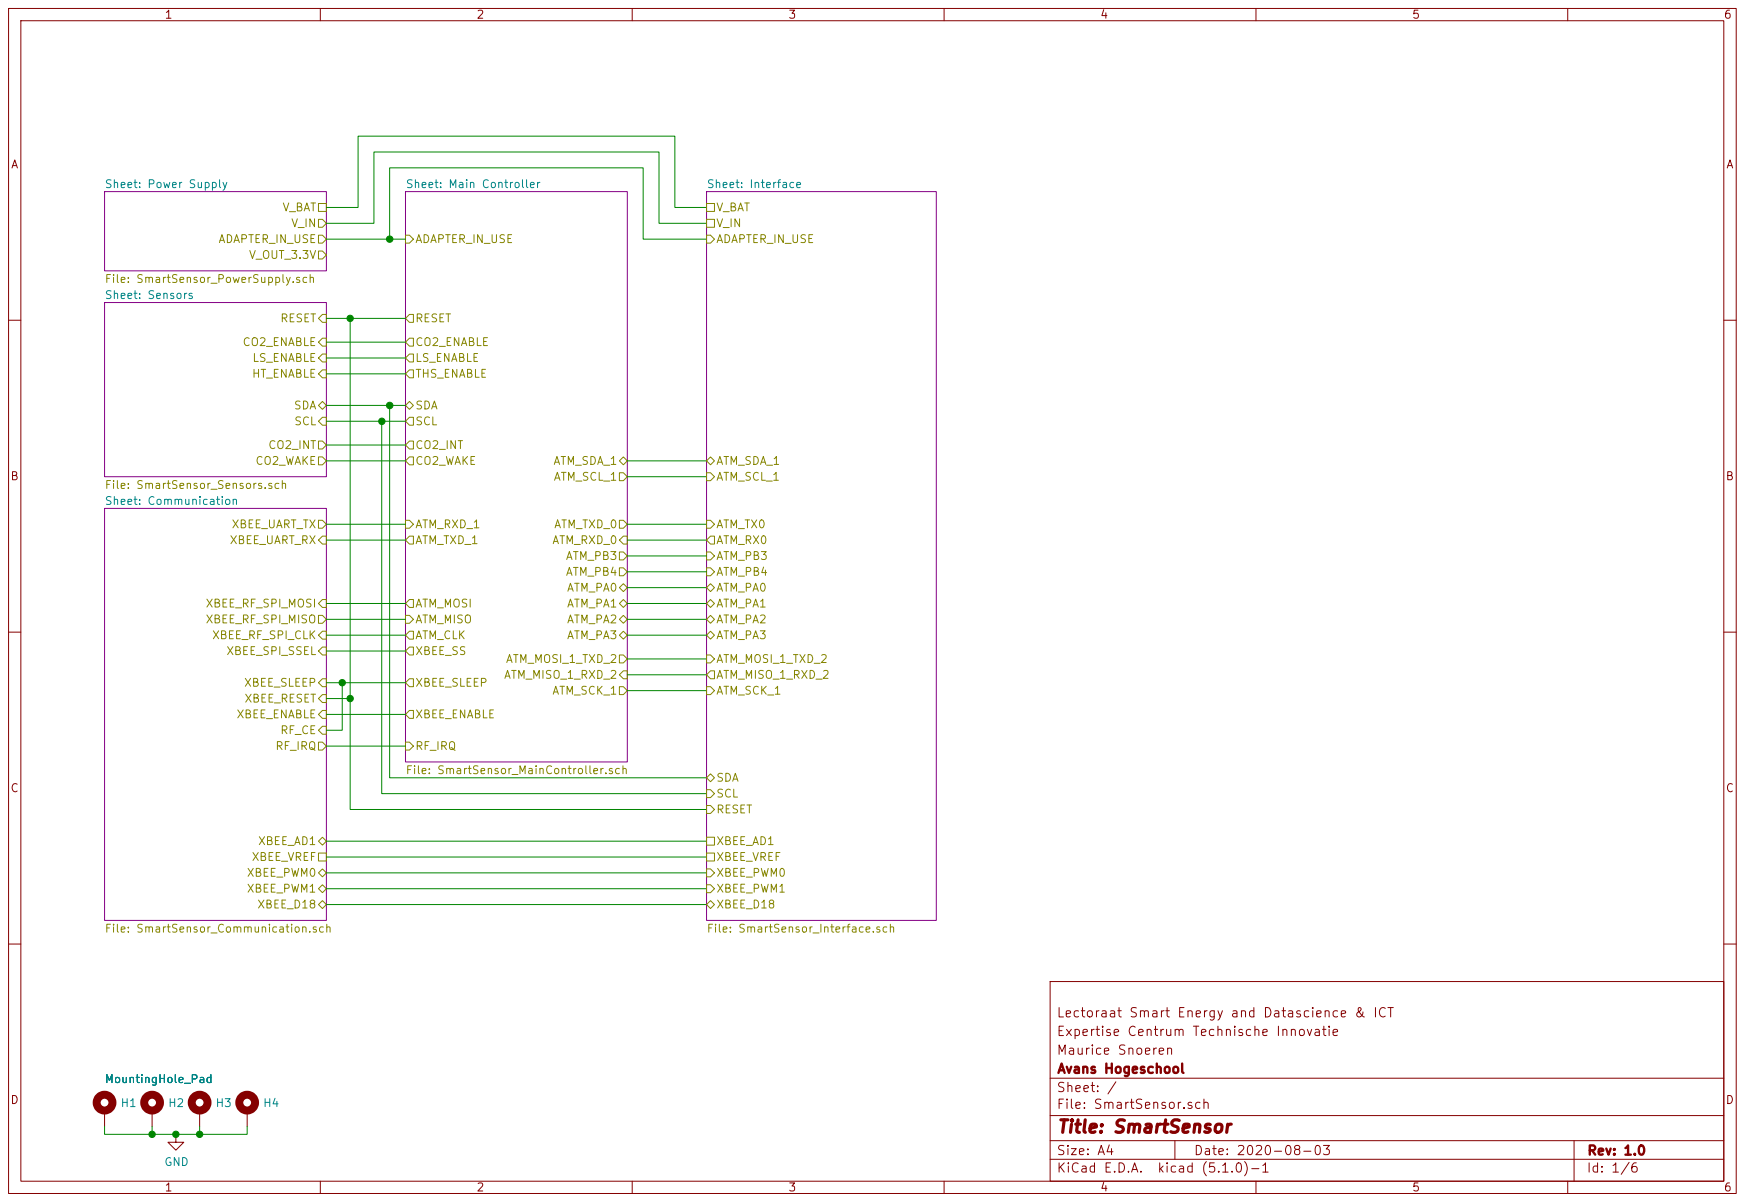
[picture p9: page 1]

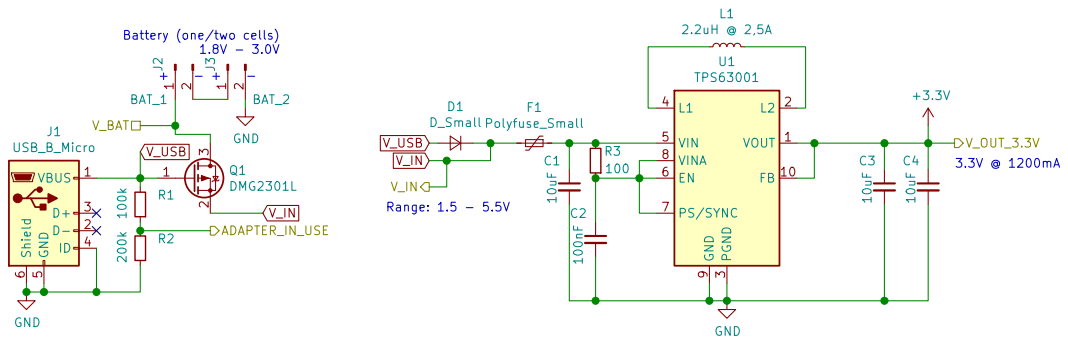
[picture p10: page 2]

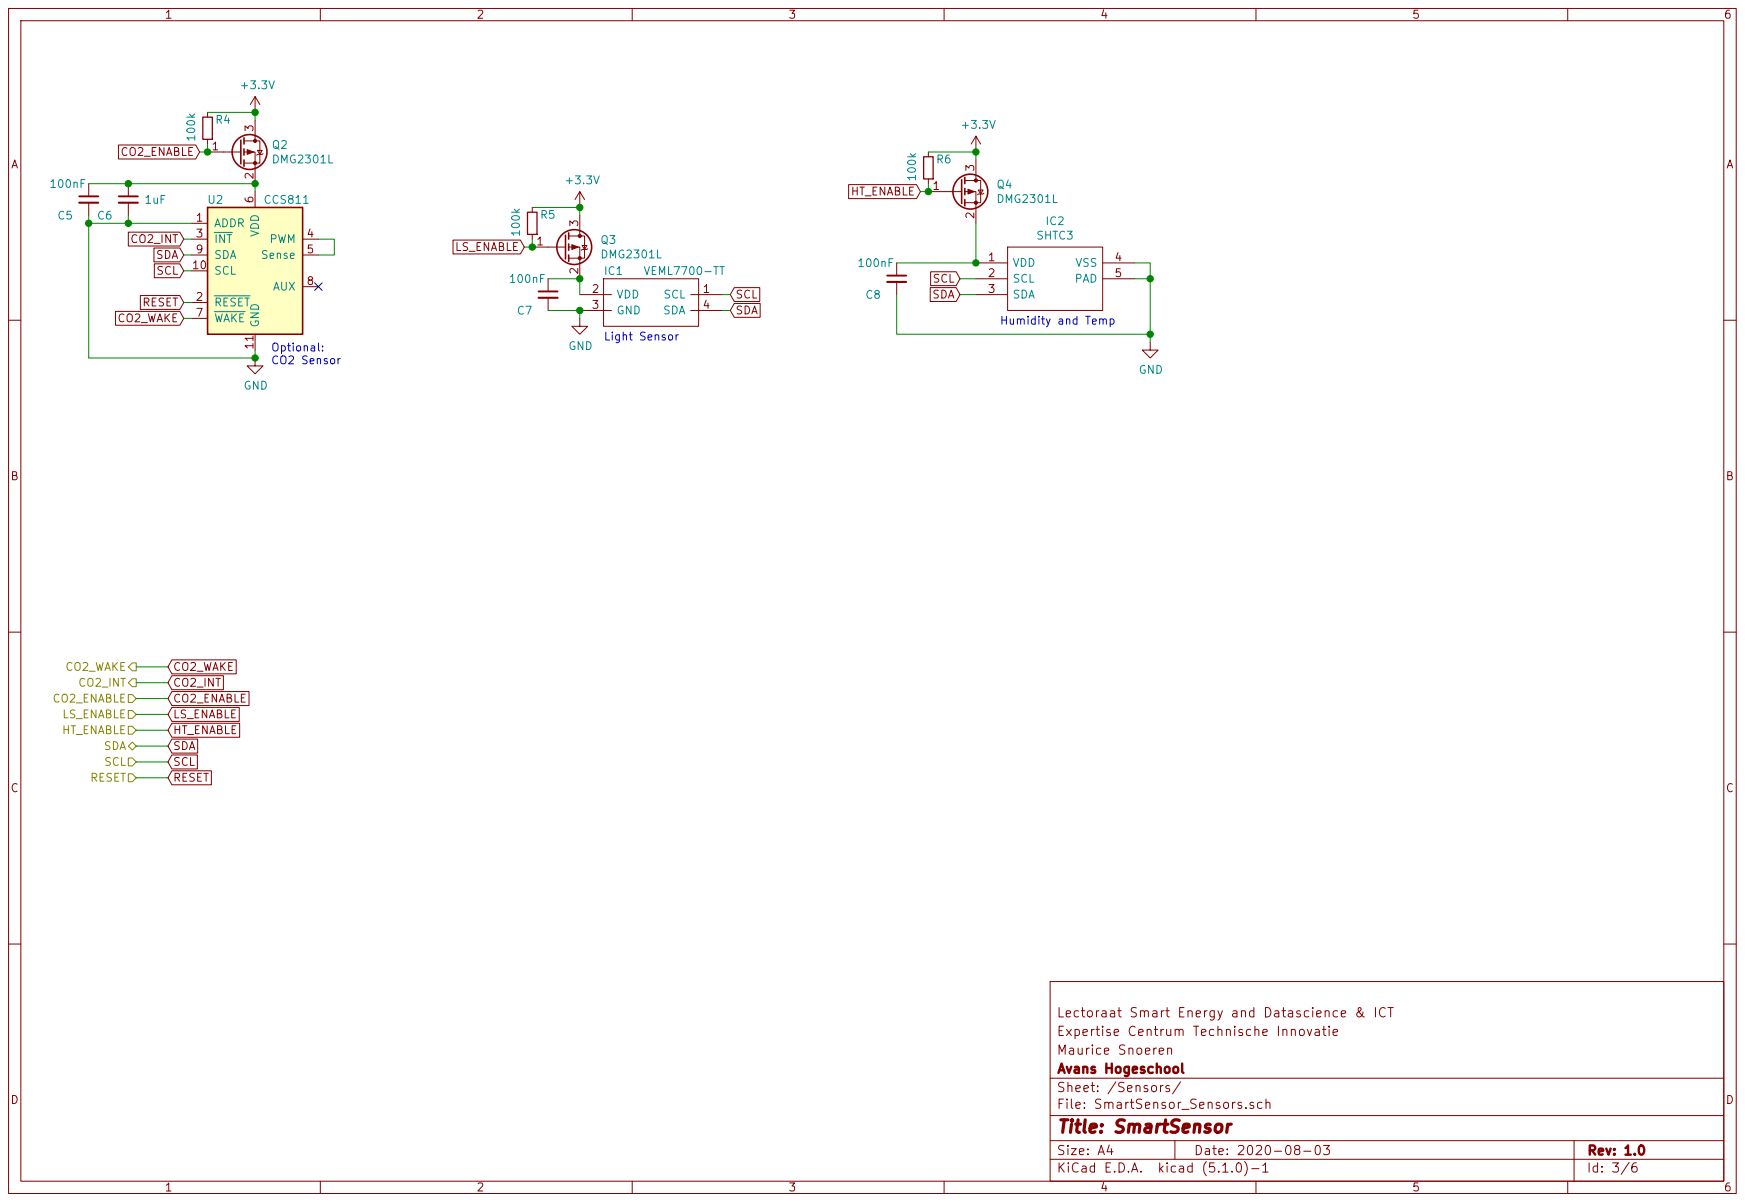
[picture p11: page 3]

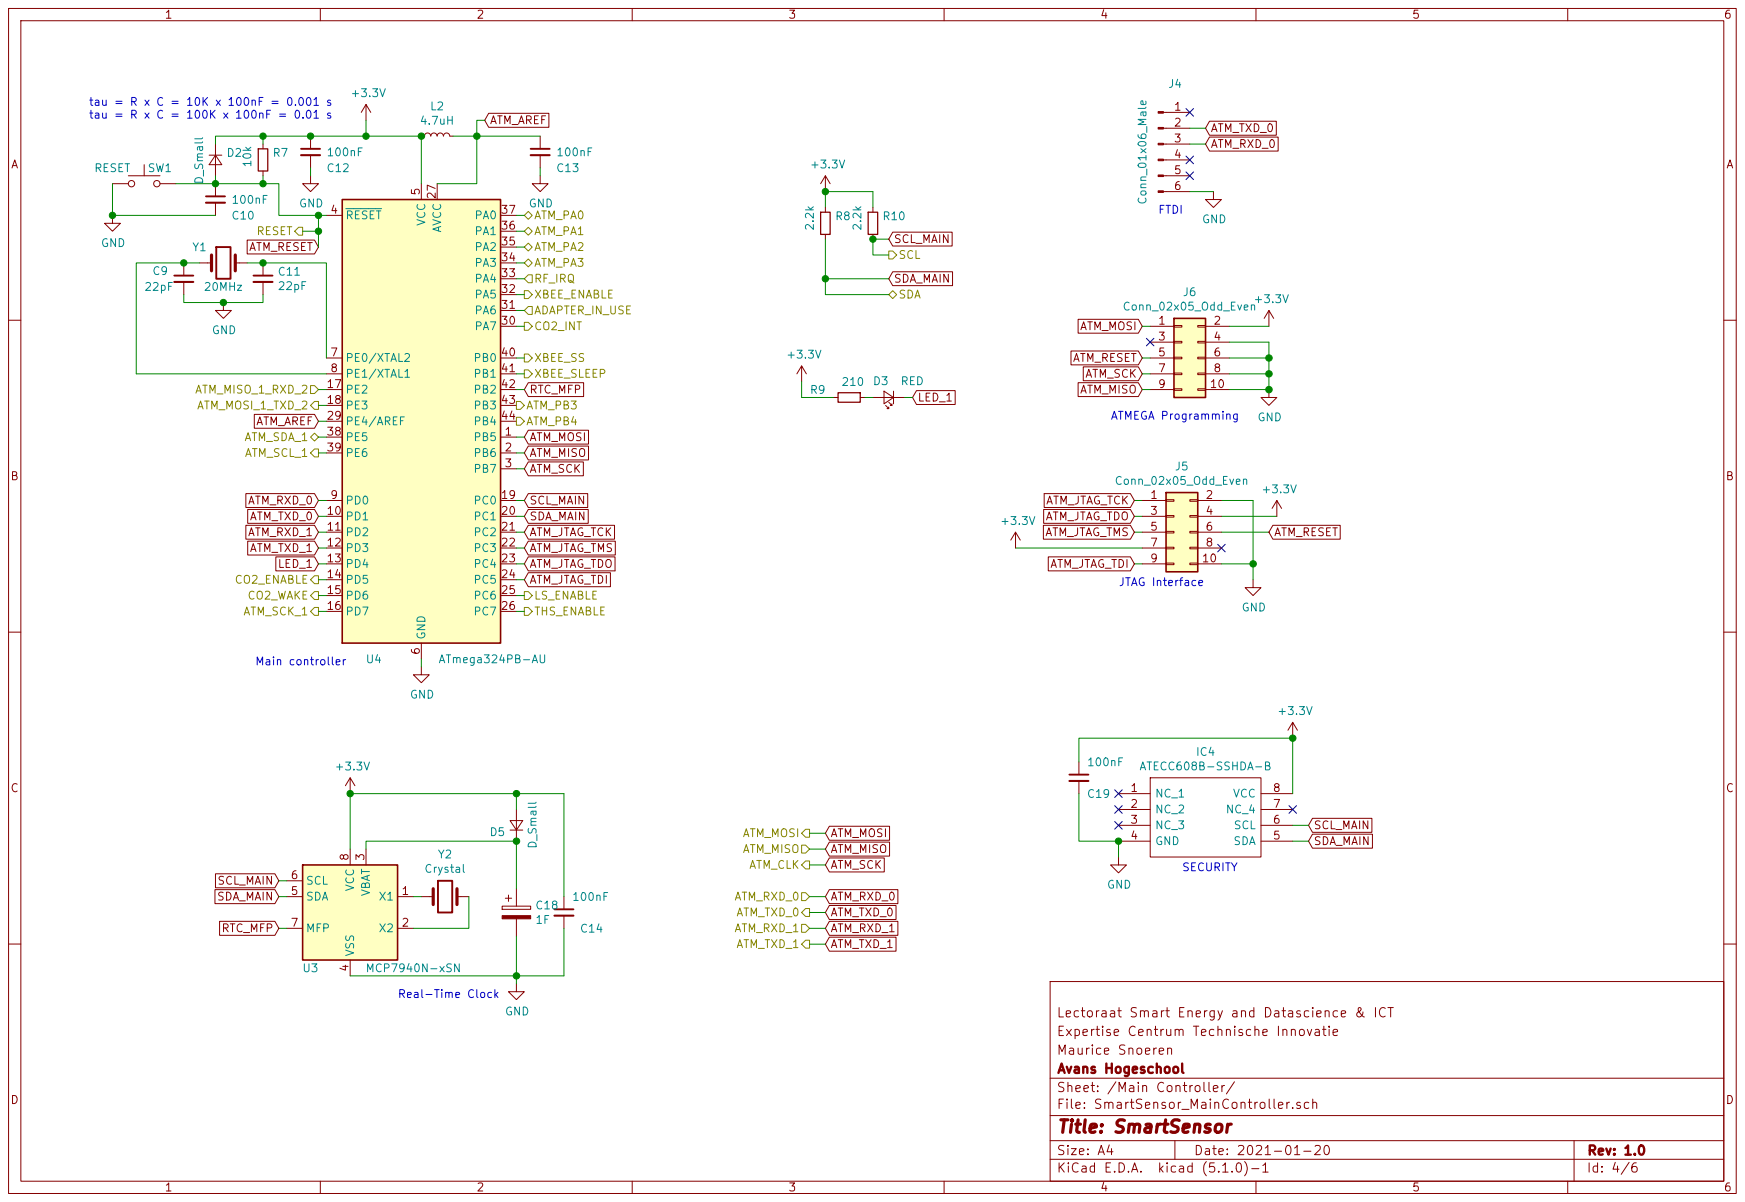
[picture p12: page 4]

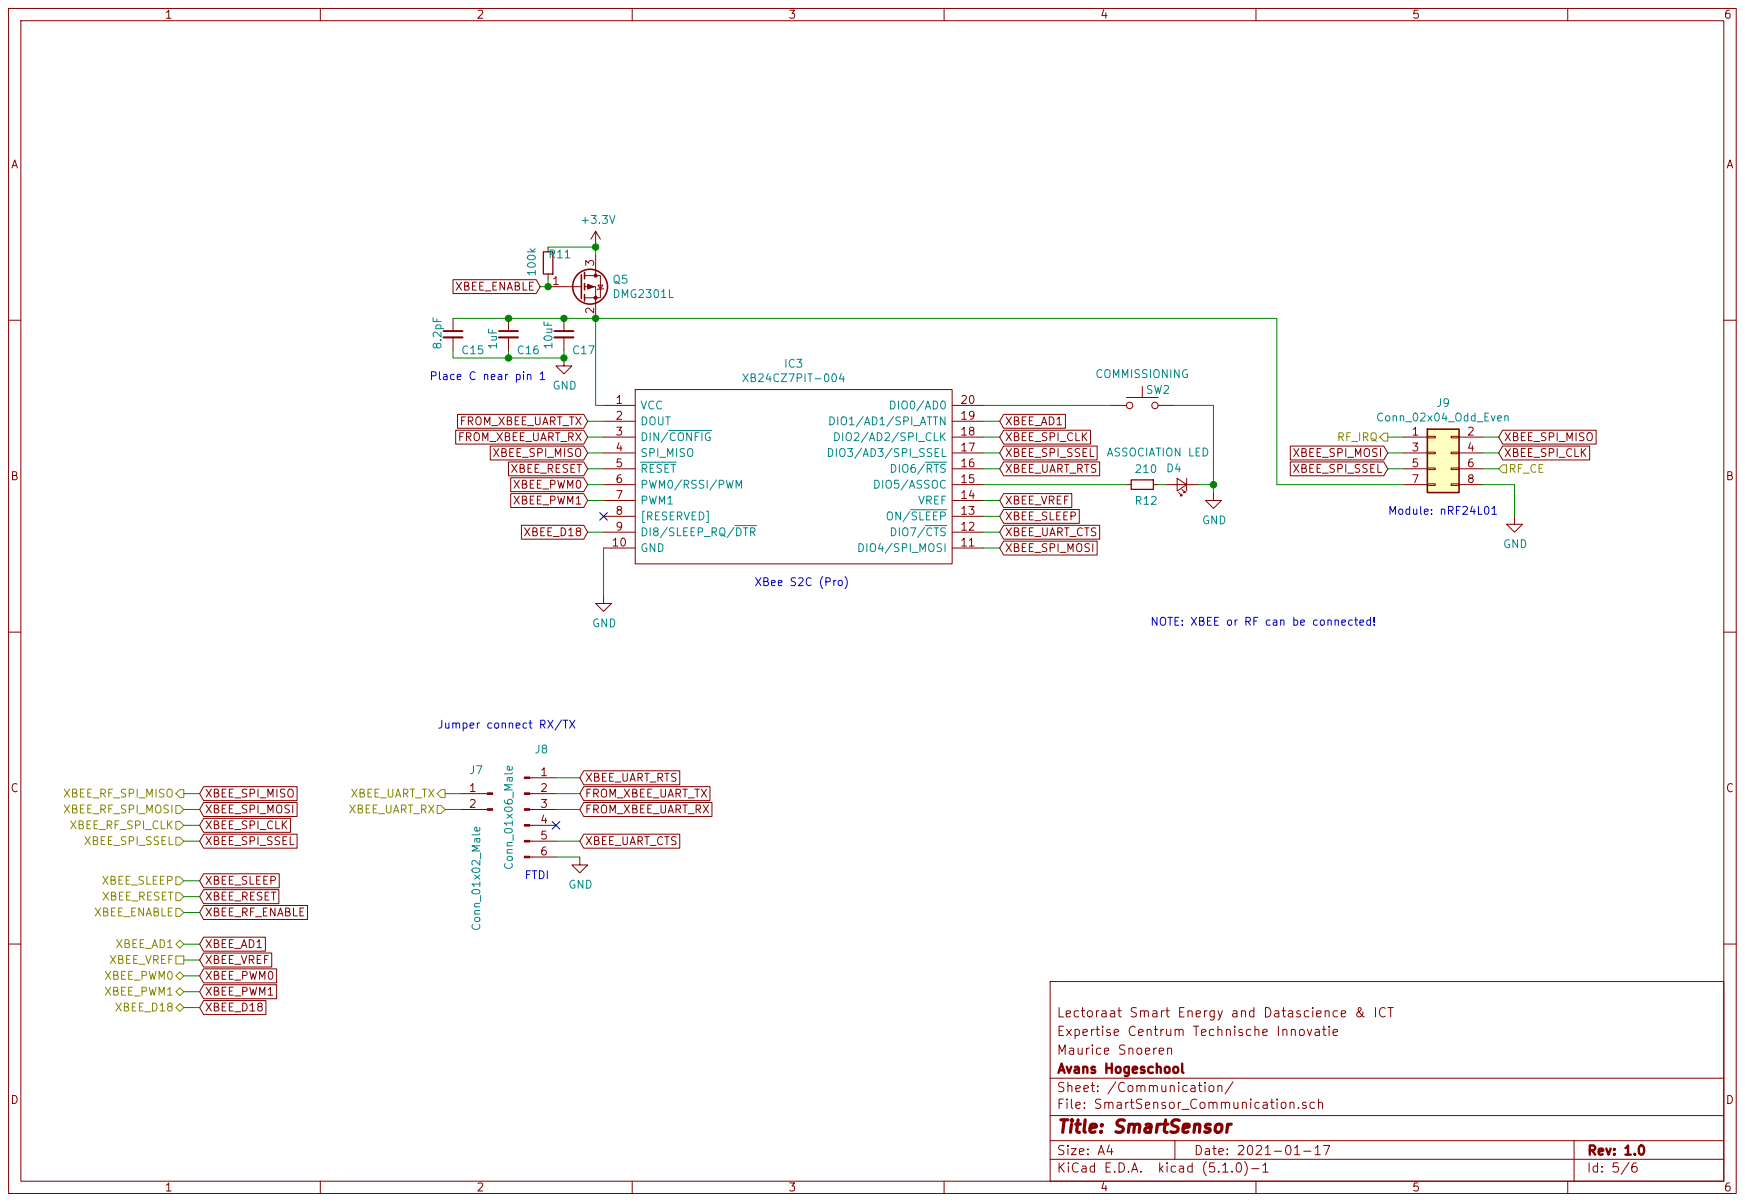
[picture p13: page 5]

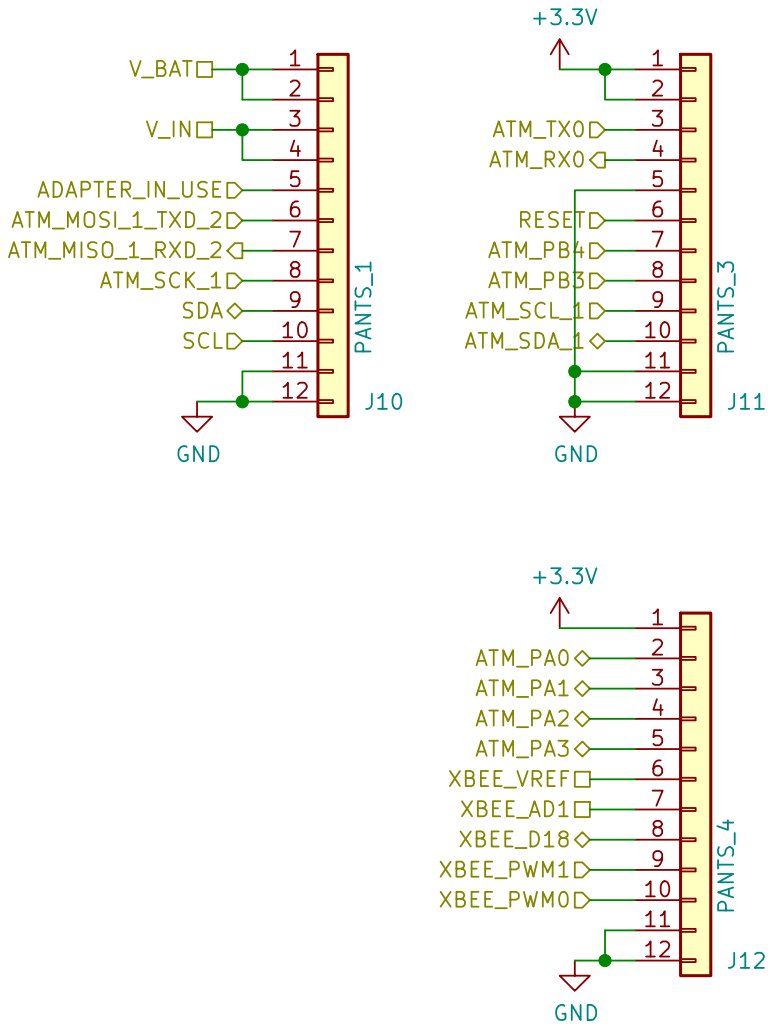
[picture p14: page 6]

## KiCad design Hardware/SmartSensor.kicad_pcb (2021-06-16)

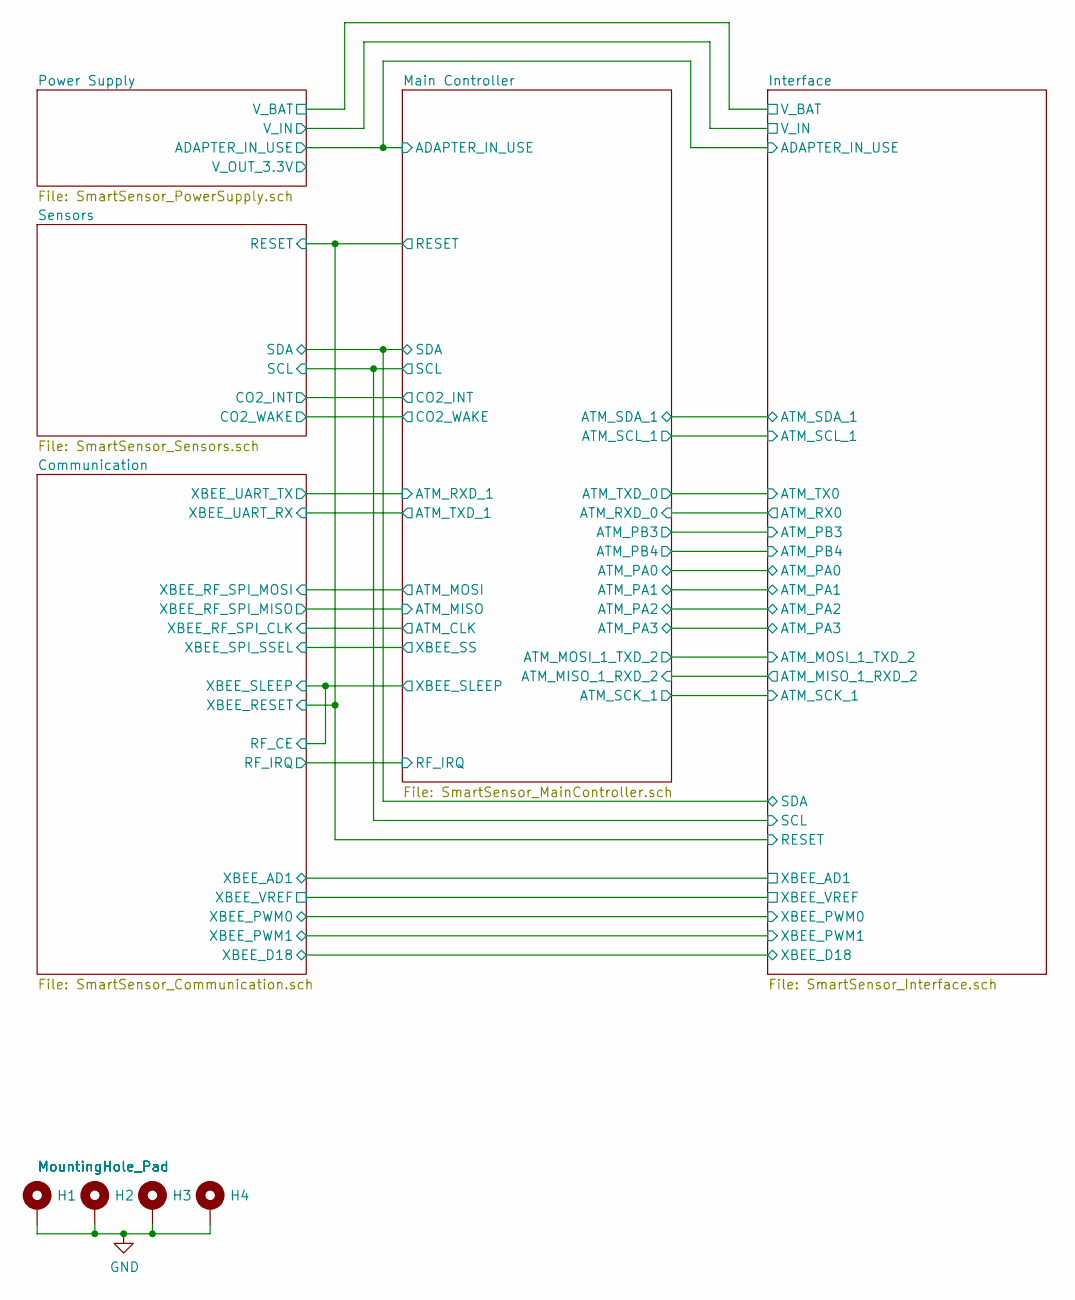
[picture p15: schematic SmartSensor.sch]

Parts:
H1, H2, H3, H4: MountingHole_Pad; MountingHole_2.2mm_M2_Pad_Via

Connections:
GND: H1.1, H2.1, H3.1, H4.1; also elsewhere on the board

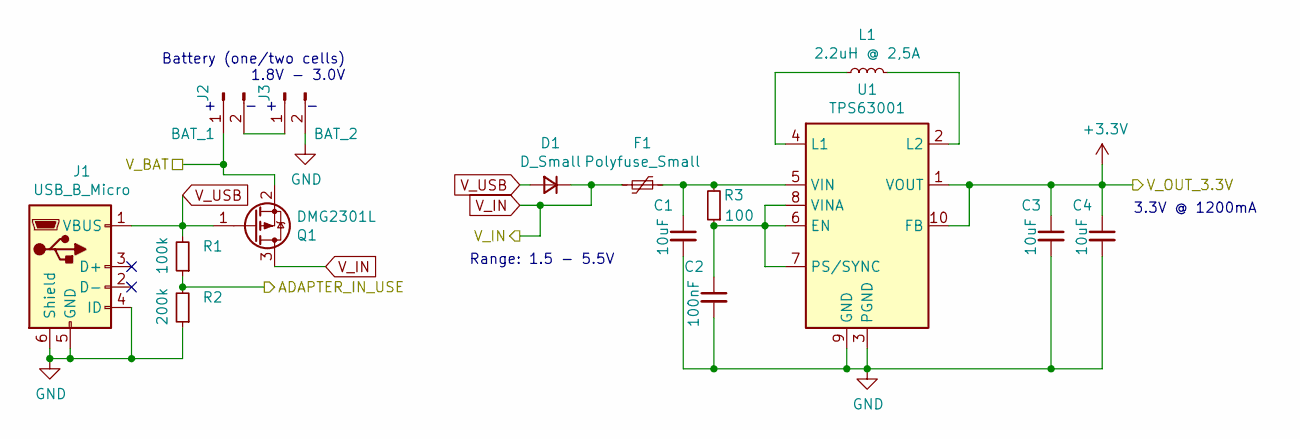
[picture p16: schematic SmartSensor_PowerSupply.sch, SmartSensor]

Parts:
C1, C3, C4: 10uF; C_0805_2012Metric
C2: 100nF; C_0805_2012Metric
D1: D_Small; D_0805_2012Metric
F1: Polyfuse_Small; Fuse_1812_4532Metric
J1: USB_B_Micro; USB_Micro-B_Amphenol_10103594-0001LF_Horizontal
J2: BAT_1; PinHeader_1x02_P2.54mm_Vertical
J3: BAT_2; PinHeader_1x02_P2.54mm_Vertical
L1: 2.2uH @ 2,5A; L_Vishay_IHLP-2020
Q1: DMG2301L; SOT-23
R1: 100k; R_0805_2012Metric
R2: 200k; R_0805_2012Metric
R3: 100; R_0805_2012Metric
U1: TPS63001; Texas_DRC0010J_ThermalVias

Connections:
+3V3: C3.1, C4.1, U1.1 (VOUT), U1.10 (FB); also elsewhere on the board
/Interface/ADAPTER_IN_USE: R1.1, R2.2; also elsewhere on the board
/Interface/V_BAT: J2.1, Q1.2 (S); also elsewhere on the board
GND: C1.2, C2.2, C3.2, C4.2, J1.4 (ID), J1.5 (GND), J1.6 (Shield), J3.2, R2.1, U1.3 (PGND), U1.9 (GND), U1.11 (PGND); also elsewhere on the board
unnamed: C1.1, F1.1, R3.2, U1.5 (VIN)
unnamed: C2.1, R3.1, U1.6 (EN), U1.7 (PS/SYNC), U1.8 (VINA)
unnamed: J2.2, J3.1
unnamed: L1.1, U1.4 (L1)
unnamed: L1.2, U1.2 (L2)
V_IN: D1.1 (K), F1.2, Q1.3 (D); also elsewhere on the board
V_USB: D1.2 (A), J1.1 (VBUS), Q1.1 (G), R1.2

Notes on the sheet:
Battery (one/two cells) 1.8V - 3.0V
3.3V @ 1200mA
Range: 1.5 - 5.5V

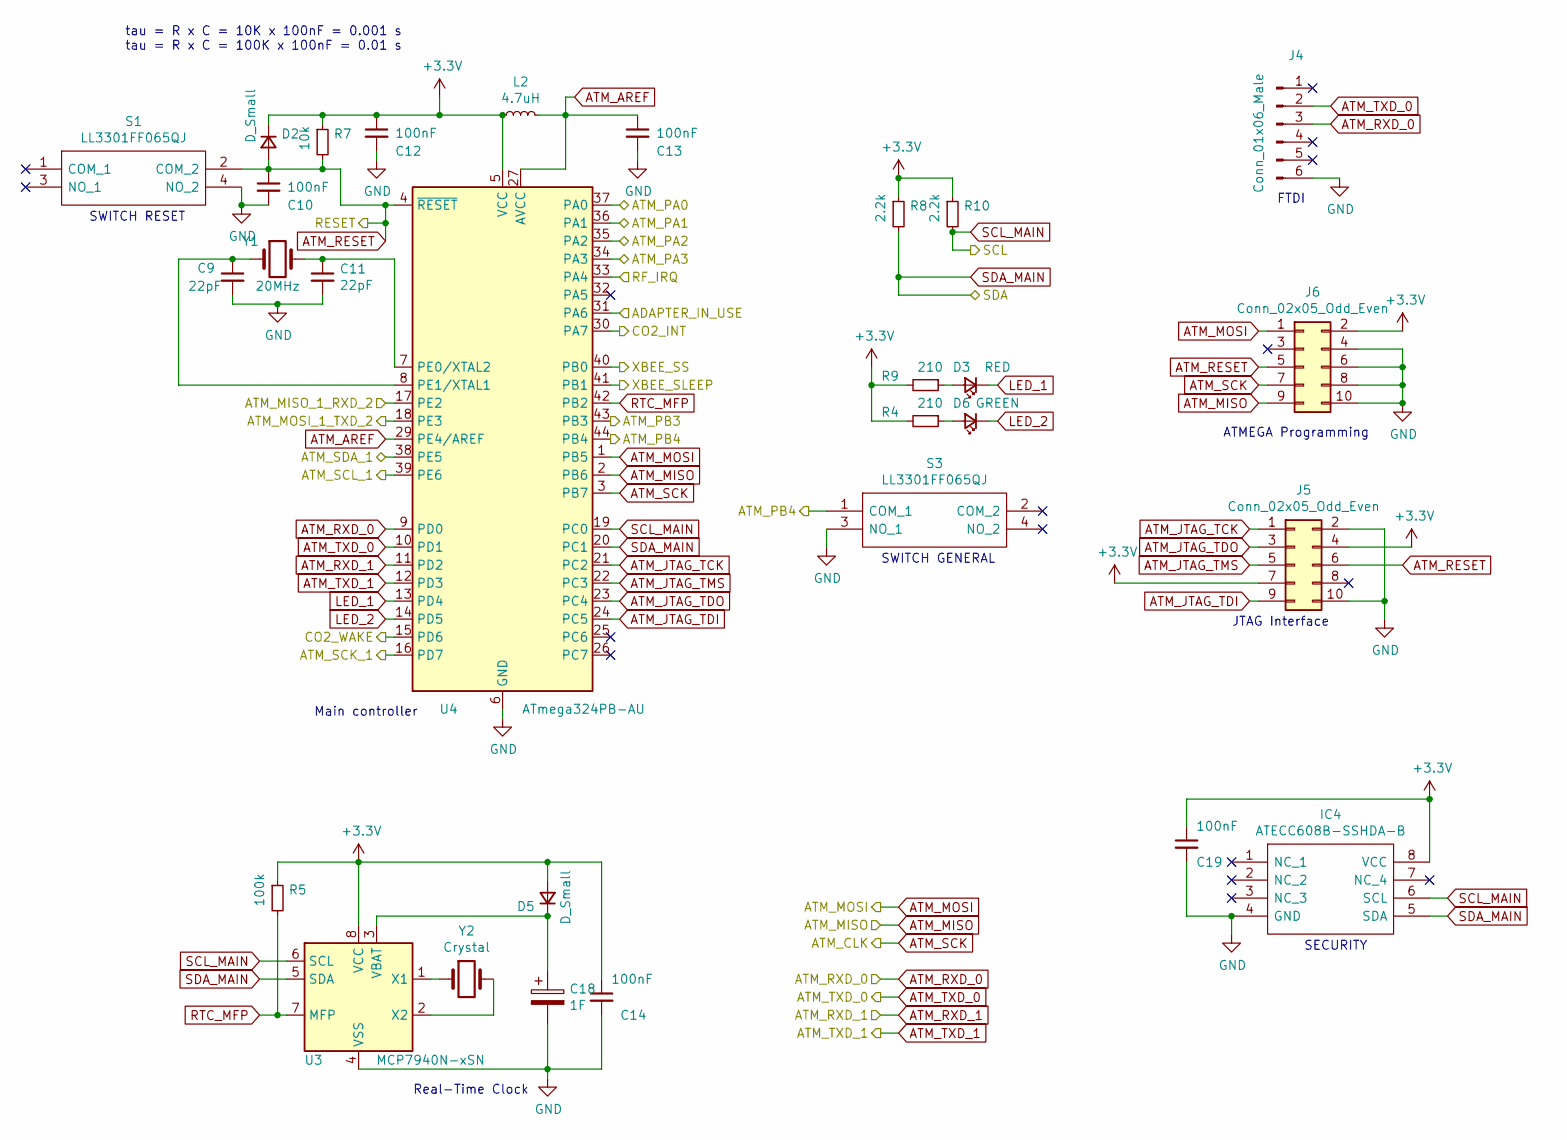
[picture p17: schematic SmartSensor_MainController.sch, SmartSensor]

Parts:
C9, C11: 22pF; C_0805_2012Metric
C10, C12, C13, C14, C19: 100nF; C_0805_2012Metric
C18: 1F; CP_Radial_D14.0mm_P5.00mm
D2, D5: D_Small; D_0805_2012Metric
D3: RED; LED_0805_2012Metric
D6: GREEN; LED_0805_2012Metric
IC4: ATECC608B-SSHDA-B; SOIC127P600X175-8N; Mouser Part Number 579-TECC608B-SSHDA-B
J4: Conn_01x06_Male; PinHeader_1x06_P2.54mm_Vertical
J5, J6: Conn_02x05_Odd_Even; PinHeader_2x05_P2.54mm_Vertical
L2: 4.7uH; L_1206_3216Metric_Pad1.42x1.75mm_HandSolder
R4, R9: 210; R_0805_2012Metric
R5: 100k; R_0805_2012Metric
R7: 10k; R_0805_2012Metric
R8, R10: 2.2k; R_0805_2012Metric
S1, S3: LL3301FF065QJ; Mouser Part Number 612-LL3301FF065QJ
U3: MCP7940N-xSN; SOIC-8_3.9x4.9mm_P1.27mm
U4: ATmega324PB-AU; TQFP-44_10x10mm_P0.8mm
Y1: 20MHz; Crystal_SMD_Abracon_ABM3-2Pin_5.0x3.2mm
Y2: Crystal; Crystal_SMD_G8-2Pin_3.2x1.5mm

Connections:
+3V3: C12.1, C14.1, C19.1, D2.1 (K), D5.2 (A), IC4.8 (VCC), J5.4, J5.7, J6.2, L2.1, R4.2, R5.1, R7.1, R8.1, R9.2, R10.1, U3.8 (VCC), U4.5 (VCC); also elsewhere on the board
/Communication/RF_IRQ: U4.33 (PA4); also elsewhere on the board
/Interface/ADAPTER_IN_USE: U4.31 (PA6); also elsewhere on the board
/Interface/ATM_MISO_1_RXD_2: U4.17 (PE2); also elsewhere on the board
/Interface/ATM_MOSI_1_TXD_2: U4.18 (PE3); also elsewhere on the board
/Interface/ATM_PA0: U4.37 (PA0); also elsewhere on the board
/Interface/ATM_PA1: U4.36 (PA1); also elsewhere on the board
/Interface/ATM_PA2: U4.35 (PA2); also elsewhere on the board
/Interface/ATM_PA3: U4.34 (PA3); also elsewhere on the board
/Interface/ATM_PB3: U4.43 (PB3); also elsewhere on the board
/Interface/ATM_PB4: S3.1 (COM_1), U4.44 (PB4); also elsewhere on the board
/Interface/ATM_SCK_1: U4.16 (PD7); also elsewhere on the board
/Interface/ATM_SCL_1: U4.39 (PE6); also elsewhere on the board
/Interface/ATM_SDA_1: U4.38 (PE5); also elsewhere on the board
ATM_AREF: C13.1, L2.2, U4.27 (AVCC), U4.29 (PE4/AREF)
ATM_JTAG_TCK: J5.1, U4.21 (PC2)
ATM_JTAG_TDI: J5.9, U4.24 (PC5)
ATM_JTAG_TDO: J5.3, U4.23 (PC4)
ATM_JTAG_TMS: J5.5, U4.22 (PC3)
ATM_MISO: J6.9, U4.2 (PB6); also elsewhere on the board
ATM_MOSI: J6.1, U4.1 (PB5); also elsewhere on the board
ATM_RESET: C10.1, D2.2 (A), J5.6, J6.5, R7.2, S1.2 (COM_2), U4.4 (~RESET); also elsewhere on the board
ATM_RXD_0: J4.3, U4.9 (PD0); also elsewhere on the board
ATM_RXD_1: U4.11 (PD2); also elsewhere on the board
ATM_SCK: J6.7, U4.3 (PB7); also elsewhere on the board
ATM_TXD_0: J4.2, U4.10 (PD1); also elsewhere on the board
ATM_TXD_1: U4.12 (PD3); also elsewhere on the board
CO2_INT: U4.30 (PA7); also elsewhere on the board
CO2_WAKE: U4.15 (PD6); also elsewhere on the board
GND: C9.2, C10.2, C11.2, C12.2, C13.2, C14.2, C18.2, C19.2, IC4.4 (GND), J4.6, J5.2, J5.10, J6.4, J6.6, J6.8, J6.10, S1.4 (NO_2), S3.3 (NO_1), U3.4 (VSS), U4.6 (GND), U4.28 (GND); also elsewhere on the board
LED_1: D3.1 (K), U4.13 (PD4)
LED_2: D6.1 (K), U4.14 (PD5)
unnamed: C9.1, U4.8 (PE1/XTAL1), Y1.1
unnamed: C11.1, U4.7 (PE0/XTAL2), Y1.2
unnamed: C18.1, D5.1 (K), U3.3 (VBAT)
unnamed: D3.2 (A), R9.1
unnamed: D6.2 (A), R4.1
unnamed: U3.1 (X1), Y2.1
unnamed: U3.2 (X2), Y2.2
RTC_MFP: R5.2, U3.7 (MFP), U4.42 (PB2)
SCL: IC4.6 (SCL), R10.2, U3.6 (SCL), U4.19 (PC0); also elsewhere on the board
SDA: IC4.5 (SDA), R8.2, U3.5 (SDA), U4.20 (PC1); also elsewhere on the board
XBEE_SLEEP: U4.41 (PB1); also elsewhere on the board
XBEE_SPI_SSEL: U4.40 (PB0); also elsewhere on the board

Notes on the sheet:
JTAG Interface
Real-Time Clock
ATMEGA Programming
FTDI
SECURITY
tau = R x C = 10K x 100nF = 0.001 s tau = R x C = 100K x 100nF = 0.01 s
Main controller
SWITCH RESET
SWITCH GENERAL

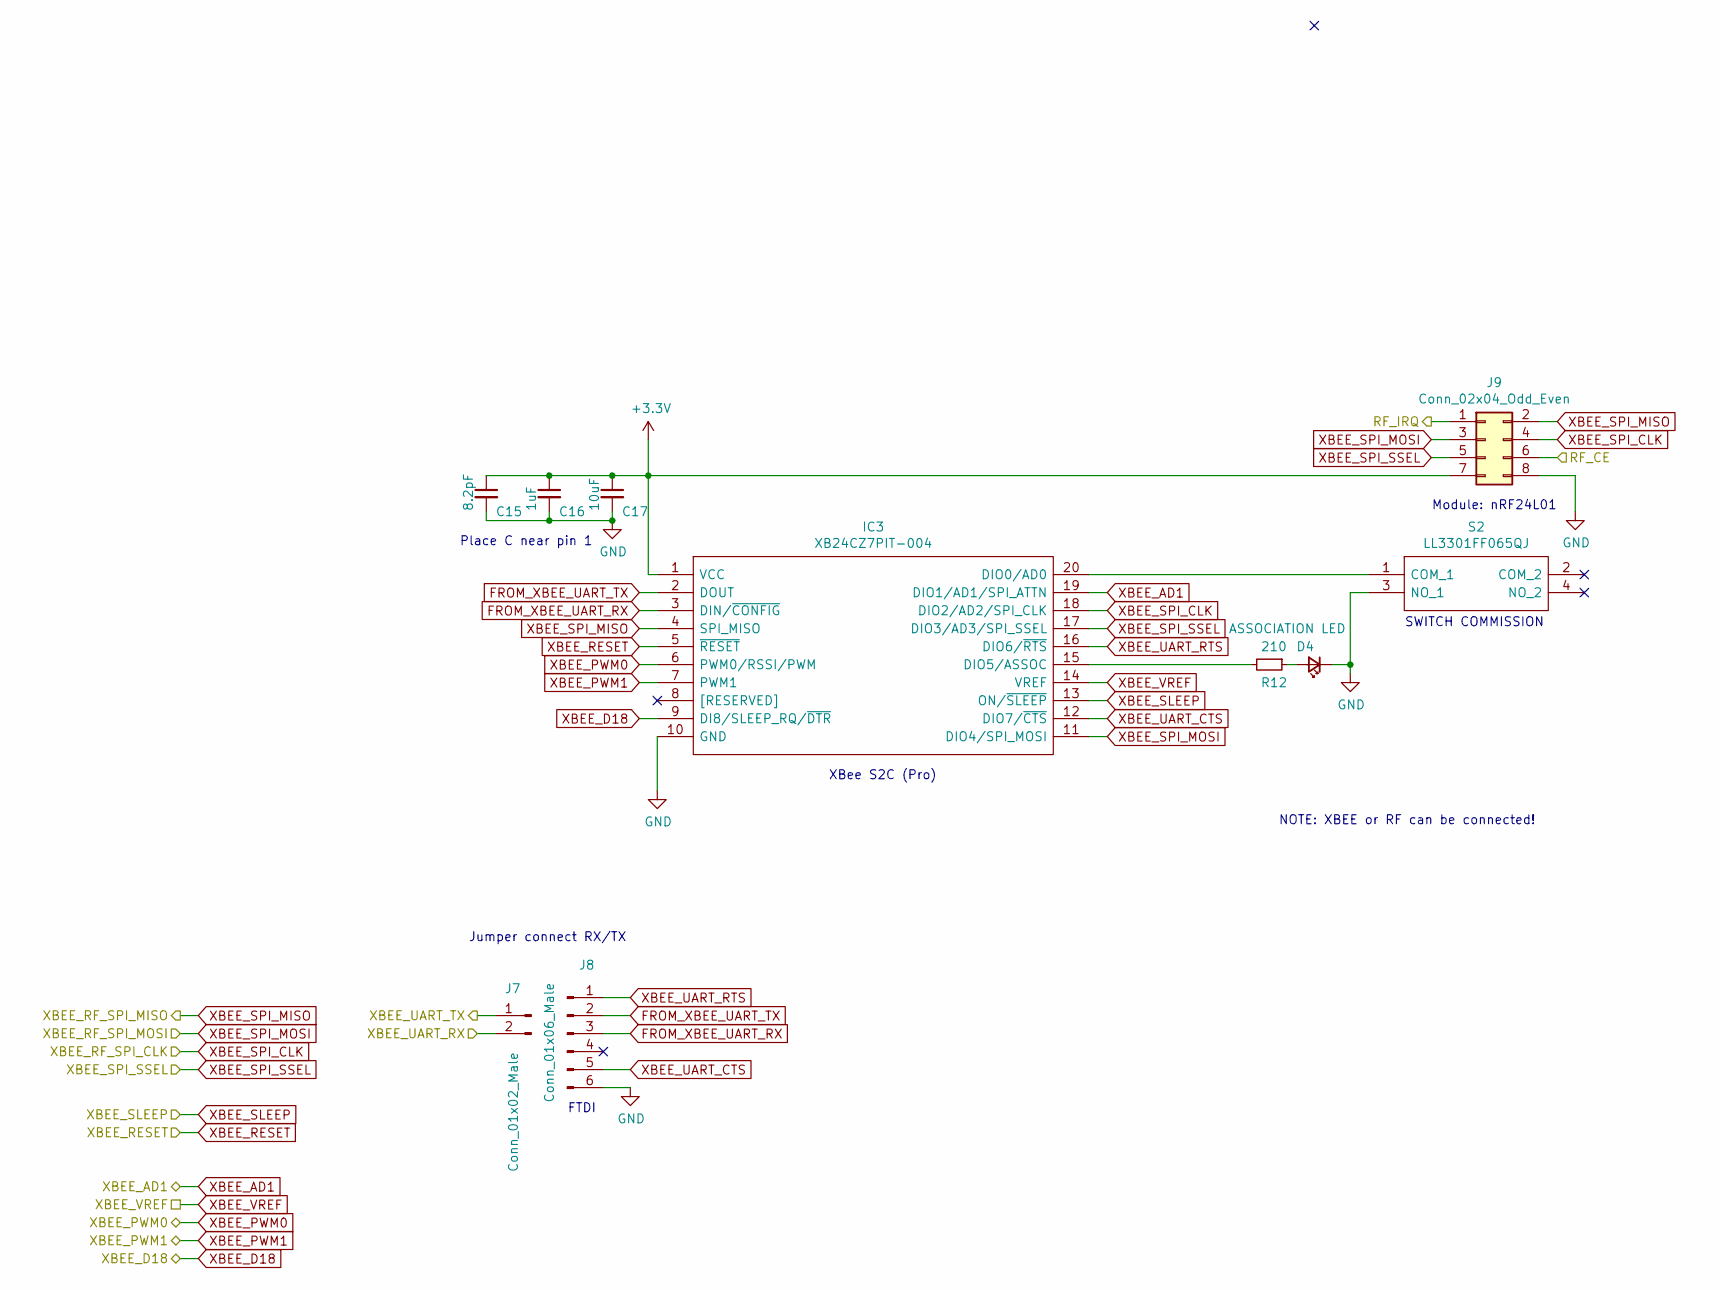
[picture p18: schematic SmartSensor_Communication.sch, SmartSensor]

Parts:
C15: 8.2pF; C_0805_2012Metric
C16: 1uF; C_0805_2012Metric
C17: 10uF; C_0805_2012Metric
D4: ASSOCIATION LED; LED_0805_2012Metric
IC3: XB24CZ7PIT-004; XB24CAPIT-001; Manufacturer_Part_Number XB24CZ7PIT-004; Mouser Part Number 888-XB24CZ7PIT-004
J7: Conn_01x02_Male; PinHeader_1x02_P2.54mm_Vertical
J8: Conn_01x06_Male; PinHeader_1x06_P2.54mm_Vertical
J9: Conn_02x04_Odd_Even; PinHeader_2x04_P2.54mm_Vertical
R12: 210; R_0805_2012Metric
S2: LL3301FF065QJ; Mouser Part Number 612-LL3301FF065QJ

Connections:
+3V3: C15.1, C16.1, C17.1, IC3.1 (VCC), J9.7; also elsewhere on the board
/Communication/RF_IRQ: J9.1; also elsewhere on the board
ATM_MISO: IC3.4 (SPI_MISO), J9.2; also elsewhere on the board
ATM_MOSI: IC3.11 (DIO4/SPI_MOSI), J9.3; also elsewhere on the board
ATM_RESET: IC3.5 (~RESET); also elsewhere on the board
ATM_RXD_1: J7.1; also elsewhere on the board
ATM_SCK: IC3.18 (DIO2/AD2/SPI_CLK), J9.4; also elsewhere on the board
ATM_TXD_1: J7.2; also elsewhere on the board
FROM_XBEE_UART_RX: IC3.3 (DIN/~CONFIG), J8.3
FROM_XBEE_UART_TX: IC3.2 (DOUT), J8.2
GND: C15.2, C16.2, C17.2, D4.1 (K), IC3.10 (GND), J8.6, J9.8, S2.3 (NO_1); also elsewhere on the board
unnamed: D4.2 (A), R12.1
unnamed: IC3.15 (DIO5/ASSOC), R12.2
unnamed: IC3.20 (DIO0/AD0), S2.1 (COM_1)
XBEE_AD1: IC3.19 (DIO1/AD1/SPI_ATTN); also elsewhere on the board
XBEE_D18: IC3.9 (DI8/SLEEP_RQ/~DTR); also elsewhere on the board
XBEE_PWM0: IC3.6 (PWM0/RSSI/PWM); also elsewhere on the board
XBEE_PWM1: IC3.7 (PWM1); also elsewhere on the board
XBEE_SLEEP: IC3.13 (ON/~SLEEP), J9.6; also elsewhere on the board
XBEE_SPI_SSEL: IC3.17 (DIO3/AD3/SPI_SSEL), J9.5; also elsewhere on the board
XBEE_UART_CTS: IC3.12 (DIO7/~CTS), J8.5
XBEE_UART_RTS: IC3.16 (DIO6/~RTS), J8.1
XBEE_VREF: IC3.14 (VREF); also elsewhere on the board

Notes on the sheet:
Place C near pin 1
XBee S2C (Pro)
Module: nRF24L01
NOTE: XBEE or RF can be connected!
Jumper connect RX/TX
FTDI
SWITCH COMMISSION

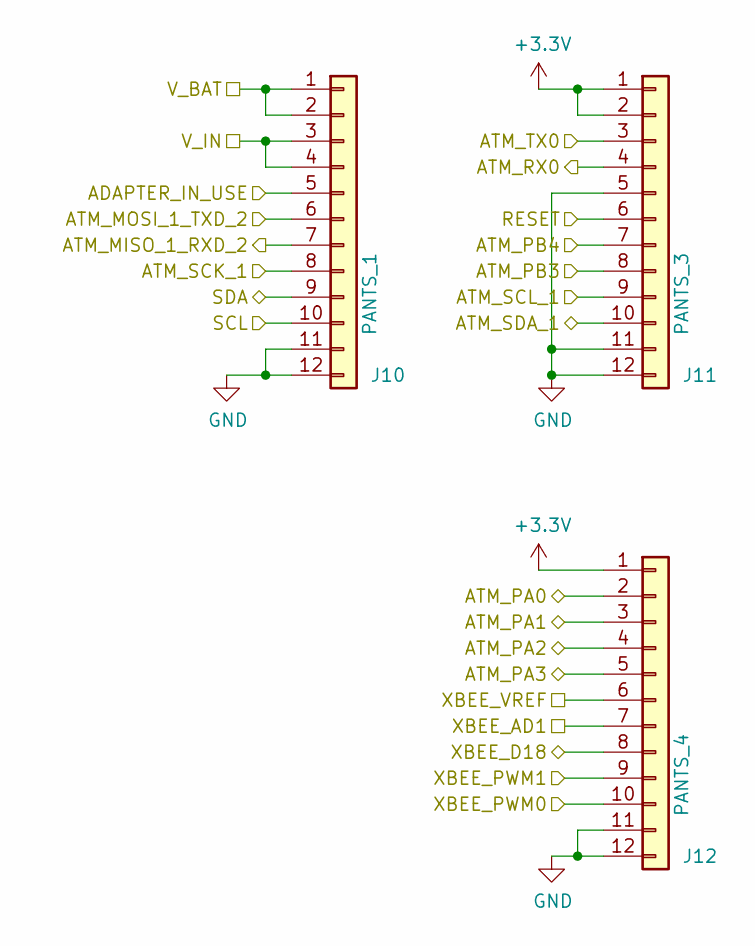
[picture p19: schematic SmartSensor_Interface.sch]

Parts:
J10: PANTS_1; PinHeader_1x12_P2.54mm_Vertical
J11: PANTS_3; PinHeader_1x12_P2.54mm_Vertical
J12: PANTS_4; PinHeader_1x12_P2.54mm_Vertical

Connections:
+3V3: J11.1, J11.2, J12.1; also elsewhere on the board
/Interface/ADAPTER_IN_USE: J10.5; also elsewhere on the board
/Interface/ATM_MISO_1_RXD_2: J10.7; also elsewhere on the board
/Interface/ATM_MOSI_1_TXD_2: J10.6; also elsewhere on the board
/Interface/ATM_PA0: J12.2; also elsewhere on the board
/Interface/ATM_PA1: J12.3; also elsewhere on the board
/Interface/ATM_PA2: J12.4; also elsewhere on the board
/Interface/ATM_PA3: J12.5; also elsewhere on the board
/Interface/ATM_PB3: J11.8; also elsewhere on the board
/Interface/ATM_PB4: J11.7; also elsewhere on the board
/Interface/ATM_SCK_1: J10.8; also elsewhere on the board
/Interface/ATM_SCL_1: J11.9; also elsewhere on the board
/Interface/ATM_SDA_1: J11.10; also elsewhere on the board
/Interface/V_BAT: J10.1, J10.2; also elsewhere on the board
ATM_RESET: J11.6; also elsewhere on the board
ATM_RXD_0: J11.4; also elsewhere on the board
ATM_TXD_0: J11.3; also elsewhere on the board
GND: J10.11, J10.12, J11.5, J11.11, J11.12, J12.11, J12.12; also elsewhere on the board
SCL: J10.10; also elsewhere on the board
SDA: J10.9; also elsewhere on the board
V_IN: J10.3, J10.4; also elsewhere on the board
XBEE_AD1: J12.7; also elsewhere on the board
XBEE_D18: J12.8; also elsewhere on the board
XBEE_PWM0: J12.10; also elsewhere on the board
XBEE_PWM1: J12.9; also elsewhere on the board
XBEE_VREF: J12.6; also elsewhere on the board

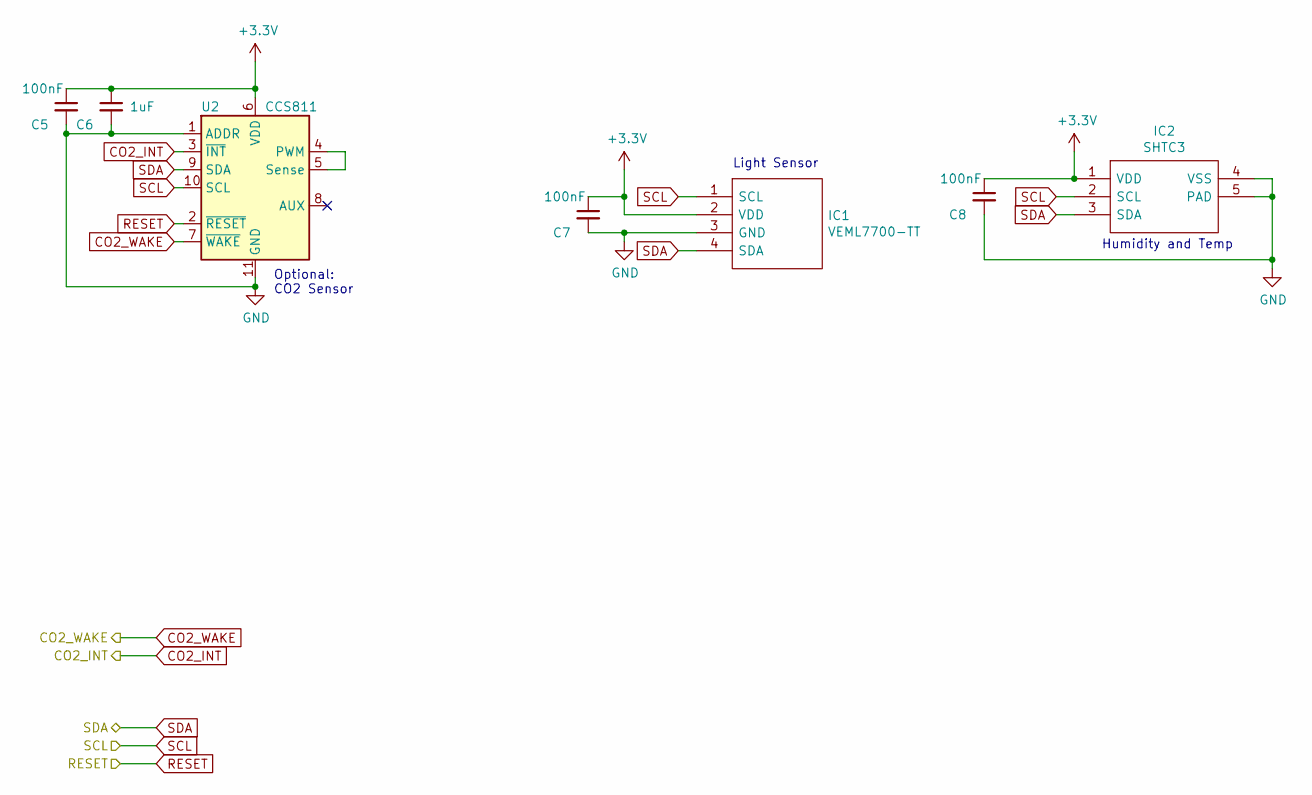
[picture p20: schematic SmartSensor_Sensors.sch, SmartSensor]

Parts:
C5, C7, C8: 100nF; C_0805_2012Metric
C6: 1uF; C_0805_2012Metric
IC1: VEML7700-TT; VEML7700; Mouser Part Number 78-VEML7700-TT
IC2: SHTC3; AMS_QFN-4-1EP_2x2mm_P0.95mm_EP0.7x1.6mm; Manufacturer_Part_Number SHTC3; Mouser Part Number 403-SHTC3
U2: CCS811; AMS_LGA-10-1EP_2.7x4mm_P0.6mm

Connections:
+3V3: C5.1, C6.1, C7.1, C8.1, IC1.2 (VDD), IC2.1 (VDD), U2.6 (VDD); also elsewhere on the board
ATM_RESET: U2.2 (~RESET); also elsewhere on the board
CO2_INT: U2.3 (~INT); also elsewhere on the board
CO2_WAKE: U2.7 (~WAKE); also elsewhere on the board
GND: C5.2, C6.2, C7.2, C8.2, IC1.3 (GND), IC2.4 (VSS), IC2.5 (PAD), U2.1 (ADDR), U2.11 (GND); also elsewhere on the board
unnamed: U2.4 (PWM), U2.5 (Sense)
SCL: IC1.1 (SCL), IC2.2 (SCL), U2.10 (SCL); also elsewhere on the board
SDA: IC1.4 (SDA), IC2.3 (SDA), U2.9 (SDA); also elsewhere on the board

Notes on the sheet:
Optional: CO2 Sensor
Light Sensor
Humidity and Temp

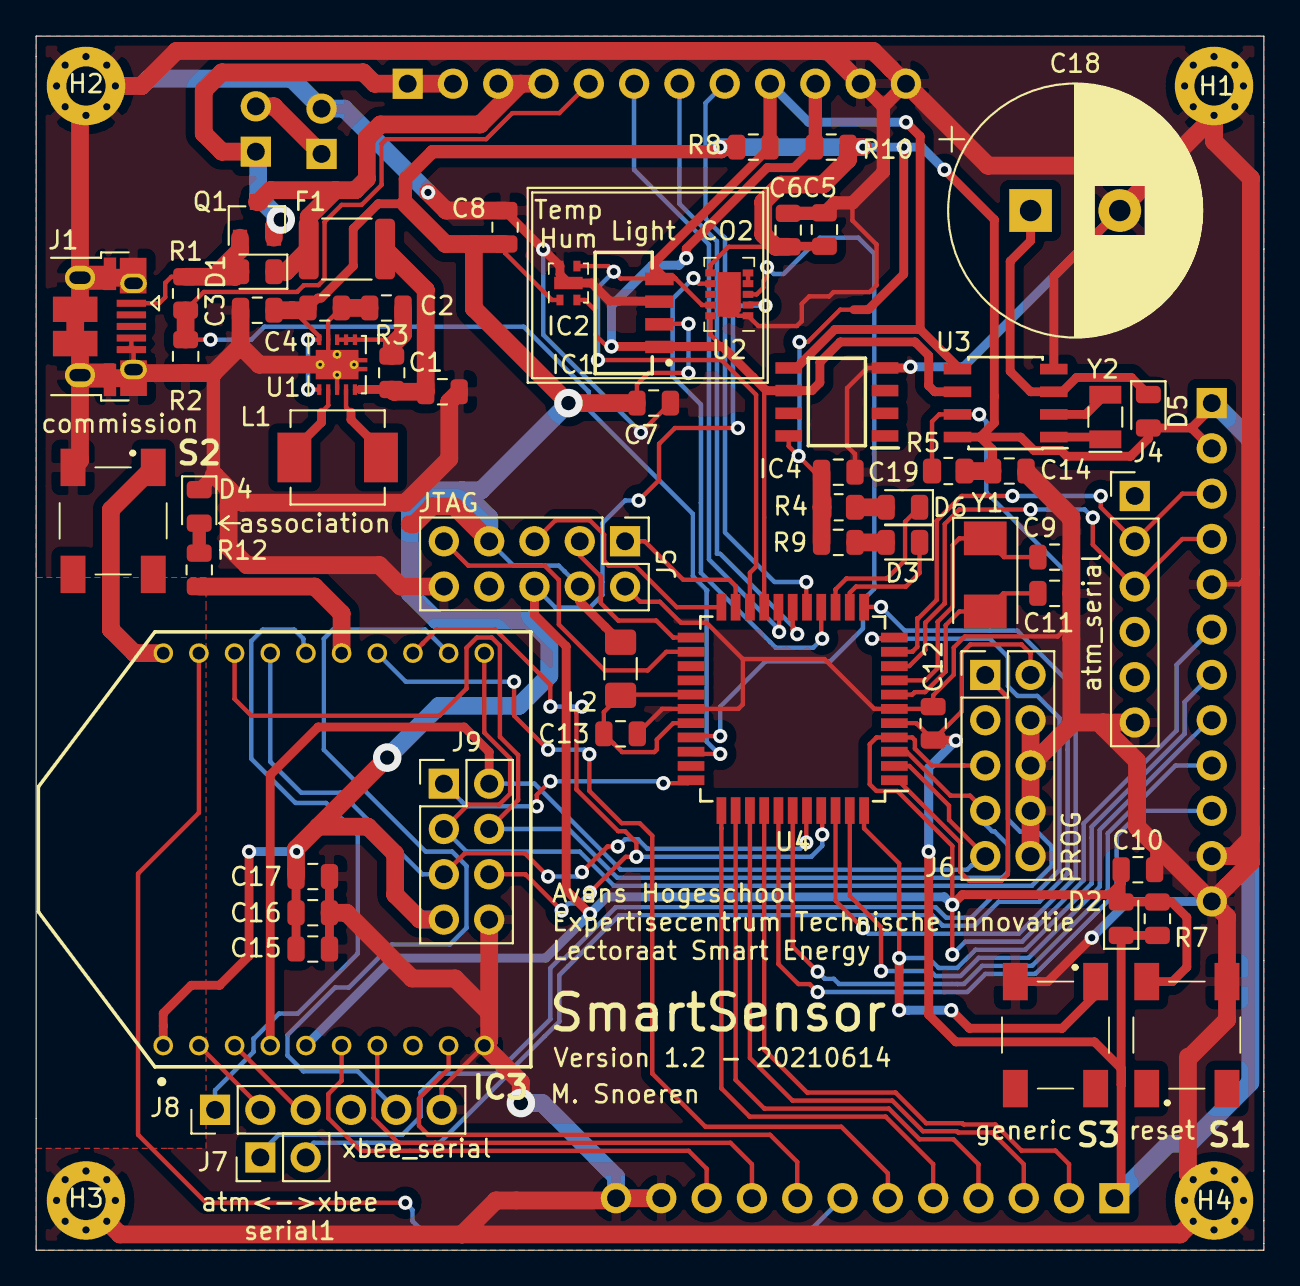
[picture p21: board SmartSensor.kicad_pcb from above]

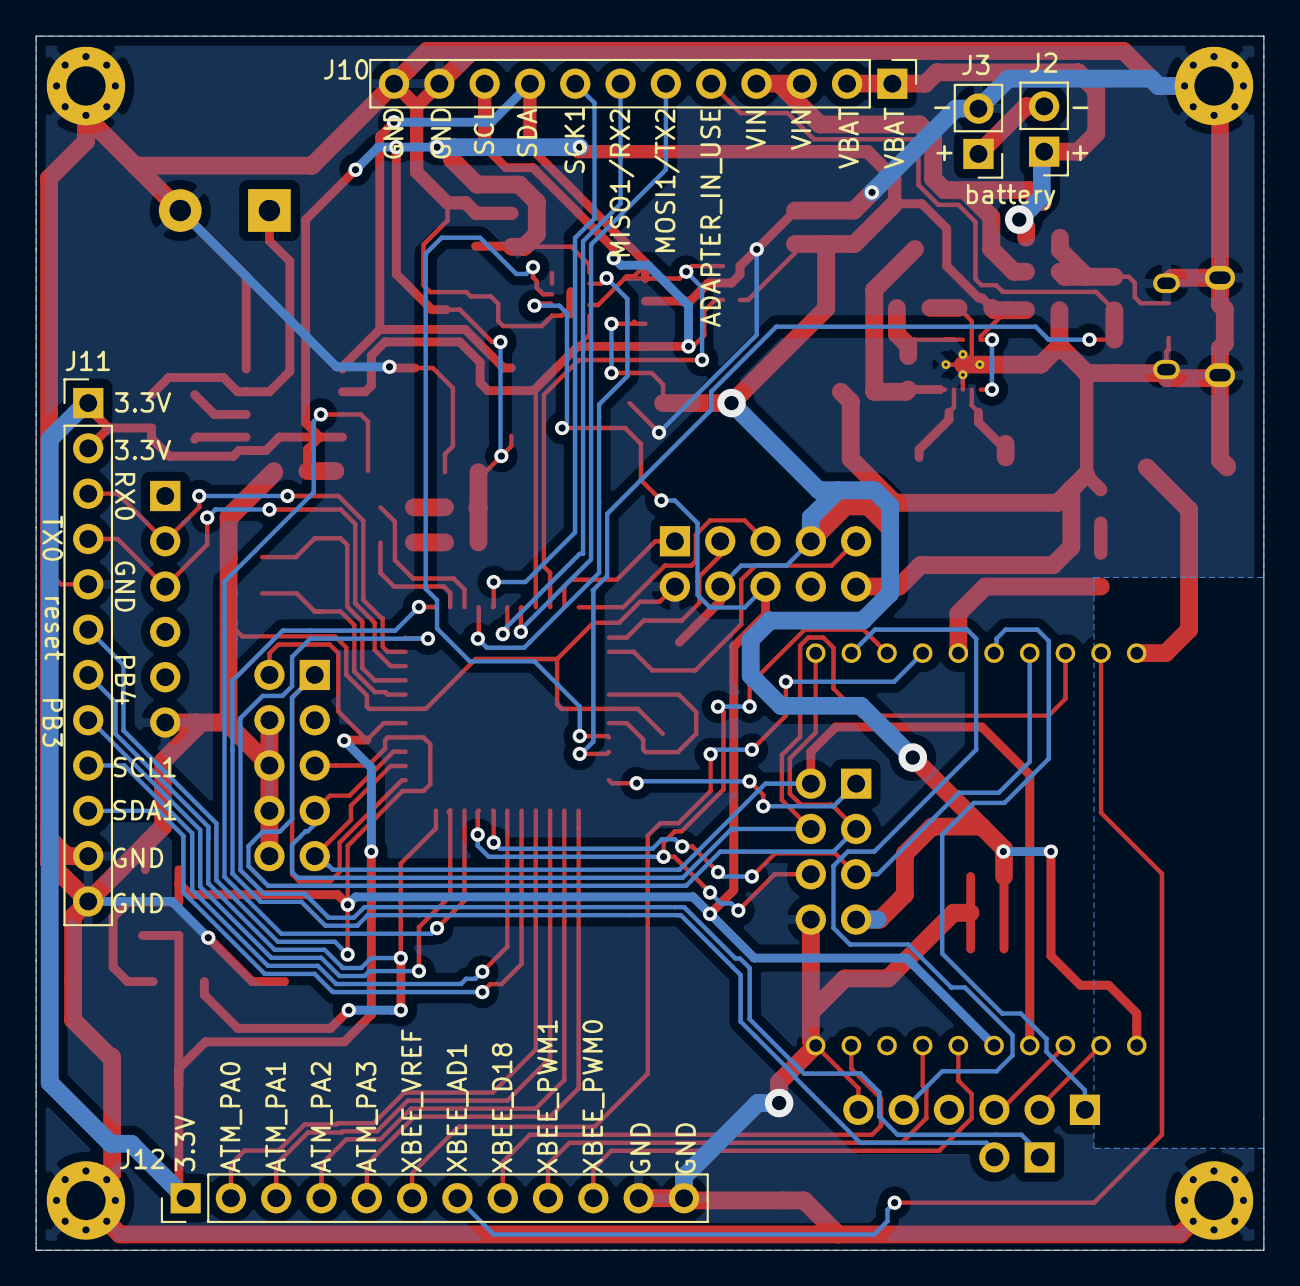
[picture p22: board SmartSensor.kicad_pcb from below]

Board: 2 copper layers, 68.8 x 68.1 mm, 68 parts (5 on the bottom side), 65 nets.

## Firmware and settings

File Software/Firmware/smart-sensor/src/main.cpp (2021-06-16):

/**
 * Entry point of the application
 * @date 12 May 2020
 * @author Patrick de Jong, Paul Hobbel, Sergen Peker, Carlos Cadel
 */
#ifndef UNIT_TEST
#include <boardsupport.h>
#include <board-support/drivers/TWIDriver.h>
#include <util/Composer.h>
#include <board-support/util/PinManager.h>

int main() {
    Composer composer;
	//SerialLogger::print("===========================================\n\nStarting Smart Sensor\n\n===========================================\n");

	//SerialLogger::info("Initializing...");
	
    TWIDriver::init();
    composer.init();

    PinManager::set_mode(STATUS_LED_1_PIN, OUTPUT);
    //PinManager::set_mode(STATUS_LED_2_PIN, OUTPUT);

    _delay_ms(1000);

	//SerialLogger::info("Starting update loop");

    for (;;) {
        composer.update();
        _delay_ms(500);
    }
    return 0;
}


#endif

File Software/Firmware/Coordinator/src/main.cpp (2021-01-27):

#include <Arduino.h>

#include <PubSubClient.h>
#include <Ethernet.h>
#include <SPI.h>


#include "config.h"

EthernetClient ethClient;
PubSubClient mqtt_client(ethClient);


byte mac[] = {  0x90, 0xA2, 0xDA, 0x0D, 0x01, 0x8B };

String data;

void setup() {
	Serial.begin(9600);
	pinMode(8, OUTPUT);
	// Ethernet shield configuration
	Ethernet.begin(mac);
	delay(1500); // Allow hardware to stabilize
	mqtt_client.setServer(MQTT_BROKER, MQTT_PORT);

	while(!mqtt_client.connected()) {
		if(mqtt_client.connect("Coordinator")) {
			mqtt_client.publish(MQTT_TOPIC,"Connected");
		} else
		{
			delay(2000);
		}
	}
	
}

void loop() {	
	if(Serial.available()>0) { 
		data = Serial.readStringUntil('}')+'}'; 
		if(data.length() > 1) {
			if(data.substring(0,1).equals("{") &&
			data.substring(data.length() - 1, data.length()).equals("}")) {
				mqtt_client.publish(MQTT_TOPIC,data.c_str()); 
			}

		}
		
	}
	Serial.flush();
	delay(10);
}

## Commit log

2019-06-26 sensor: add schematics
    [SmartSensor.kicad_pcb, SmartSensor.sch, SmartSensor_bom.xlsx]
2019-06-26 sensor: add source files
2019-06-26 git: add .gitignore
    Add gitignore for KiCAD and platformIO projects.
2019-06-27 delay: increment startup time
    [SmartSensor.kicad_pcb, SmartSensor.sch]
2019-11-01 schematics: update the schematics to v3
    Update schematics to version 3.
    [SmartSensor.kicad_pcb, SmartSensor.sch]
2019-11-07 schematics: implement version 3
    Implement the version 3 schematics.
    [SmartSensor.kicad_pcb, SmartSensor.sch]
2019-11-08 schematics: implement smart sensor v4
    Implement version 4 in hardware.
    [SmartSensor.kicad_pcb, SmartSensor.sch]
2019-12-06 hardware: update hardware
    Update the smart sensor hardware.
    [SmartSensor.kicad_pcb, SmartSensor.sch]
2019-12-06 software: reset the software
    Reset the software to a new base.
    [main.cpp]
2019-12-16 main: update device initialisation
    Add device driver initialisation.
2019-12-17 app: implement application as a singleton
    Implement the smart sensor as a singleton.
2019-12-17 init: initialize the XBee device driver
    Initialize the XBee device driver.
2020-11-27 Renamed some dirs
    [SmartSensor.kicad_pcb, SmartSensor.sch, SmartSensor_bom.xlsx]
2020-12-15 Added Smart-Sensor Firmware with Boardsupport
2021-01-27 Removing old hardware
    [SmartSensor.kicad_pcb, SmartSensor.sch, SmartSensor_bom.xlsx]
2021-01-27 Updated the hardware to version 1.0
    [SmartSensor BoM.xlsx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]
2021-02-25 Added the board version 1.0 to the board-support, not ready yet.
2021-03-01 Added board version 1.0 as a target.
    Code compiles, unable to read sensor.
2021-03-20 Modified hardware and fixed errors found in v1.0
    [SmartSensor BoM.xlsx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]
2021-03-20 Updated to the board v1.1
2021-04-28 Added current development
2021-06-10 Added timestamp to the measurements, so devices with a wrong time are also able to connect
2021-06-16 Added final version 1.2 to the repository
    [SmartSensor BoM.xlsx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]

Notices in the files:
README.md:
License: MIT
